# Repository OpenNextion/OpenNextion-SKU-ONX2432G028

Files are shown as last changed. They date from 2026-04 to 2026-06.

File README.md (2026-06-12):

[**English**](./README.md) | [简体中文](./README.zh-CN.md)

# ONX2432G028

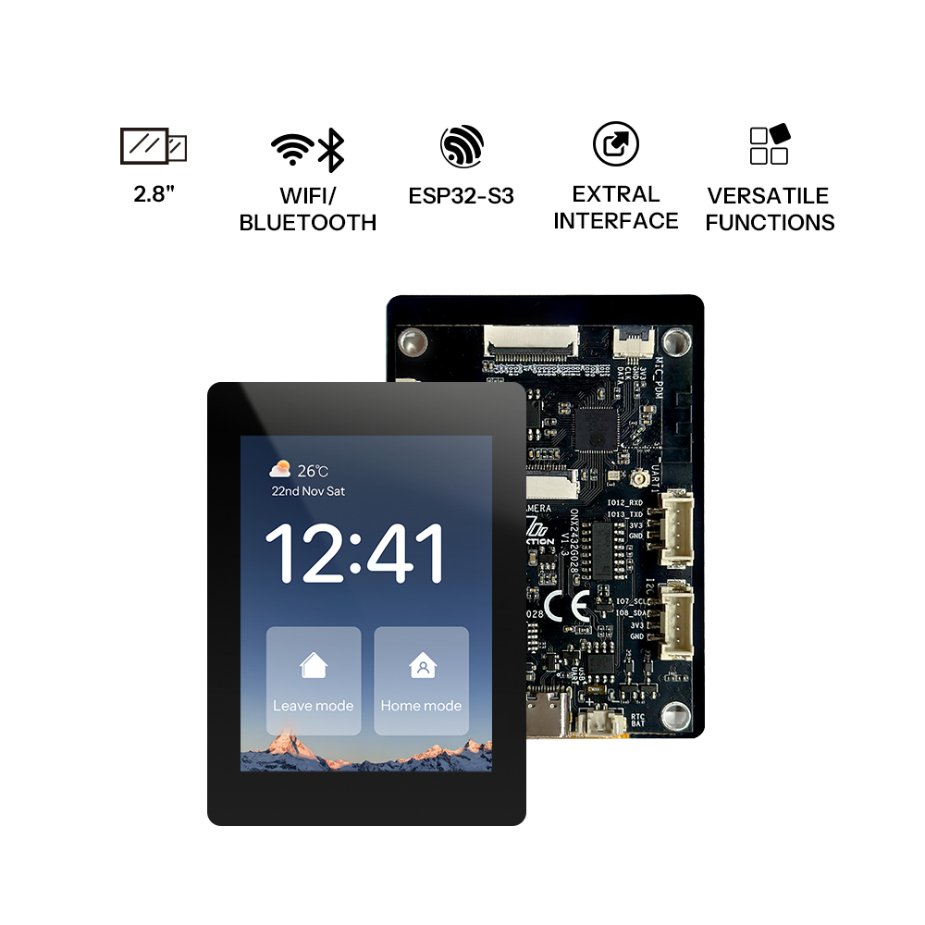
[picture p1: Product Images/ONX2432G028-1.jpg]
ONX2432G028


## Overview

`ONX2432G028` is a 2.8-inch Open Nextion HMI development board based on `ESP32-S3R8`. It integrates a capacitive touch display, `2.4 GHz Wi-Fi`, `Bluetooth 5 LE`, `MicroSD`, camera, microphone, speaker, battery management, and multiple expansion interfaces, making it suitable for HMI panels, IoT terminals, multimedia interaction, and rapid prototyping.

This repository collects product images, mechanical drawings, schematics, PCB files, certification documents, datasheets, USB-to-serial drivers, and example projects for both `ESP-IDF` and `ESP-Arduino`, so users can download and start development more easily.

## Purchase Links

- Product: [Open Nextion 2.8" Genius Series ESP32-S3 LCD Touchscreen Development Board](https://itead.cc/product/open-nextion-2-8-genius-series-esp32-s3-lcd-touchscreen-development-board/)
- Optional Audio Accessory: [Nextion BOX Speaker](https://itead.cc/product/nextion-box-speaker/)
- Optional Microphone Accessory: [Nextion Dual MIC Board](https://itead.cc/product/nextion-dual-mic-board/)
- Optional Expansion Accessory: [Nextion IO Adapter V2](https://itead.cc/product/nextion-io-adapter-v2/)

## Hardware Specifications

The following specifications are compiled from the official Wiki and the files included in this repository:

| Item | Specification |
| :--- | :--- |
| Model | `ONX2432G028` |
| MCU | `ESP32-S3R8`, Xtensa LX7 dual-core, up to `240 MHz` |
| Flash | `16 MB` |
| PSRAM | `8 MB` |
| Display Size | `2.8"` |
| Resolution | `240 x 320` |
| Colors | `262K` |
| Brightness | `300 nit` |
| Touch Type | Capacitive touch |
| LCD Driver | `ST7789` |
| Touch Driver | `CST826` |
| Wireless | `2.4 GHz Wi-Fi` + `Bluetooth 5 LE` |
| Power Input | `DC 5V/1A` |
| Battery Support | `3.7V` Li-ion battery interface with charging management, plus `3V` RTC backup battery support |
| Main Interfaces | `USB-C`, Grove `I2C`, Grove `UART1`, `MicroSD`, camera interface, PDM microphone interface, speaker interface, 24-pin GPIO, external antenna connector |
| Operating Temperature | `-20 to 70 C` |
| Storage Temperature | `-30 to 80 C` |
| Weight | Net weight about `47 g`, gross weight about `100.5 g` |

## Key Features

- Built on `ESP32-S3` for connected applications with graphical user interfaces.
- Onboard `2.8"` capacitive touch display, suitable for control panels, dashboards, and interactive terminals.
- Supports `MicroSD`, camera, `PDM` microphone, and speaker expansion for multimedia and voice-interaction projects.
- `USB-C` is used for power, firmware flashing, and serial logs, and supports automatic download mode.
- Includes an onboard antenna and a reserved external antenna connector for wireless applications.
- Supports Li-ion battery power and RTC backup battery, useful for portable and offline-clock scenarios.

## Repository Contents

| Folder | Description |
| :--- | :--- |
| `Certifications/` | Certification and compliance documents |
| `Datasheets/` | Datasheets for key components such as `ESP32-S3`, `ST7789`, `CST826`, `PCF8574`, and `IP4054V` |
| `Drawings/` | Mechanical dimension file, `2D` drawing, and `3D` model |
| `Example Programs/` | Example projects for `ESP-IDF` and `ESP-Arduino` |
| `LTA Announcement/` | Official announcement document |
| `Product Images/` | Product photos |
| `Schematic & Layout_/` | Schematics and PCB layout files |
| `USB-to-Serial Driver/` | USB-to-serial drivers for Windows, macOS, and Linux |

## Example Projects

`Example Programs/` contains two sets of ready-to-use examples:

- `ESP-IDF/`: native ESP-IDF projects, suitable for production firmware, component-based development, and projects that need the full ESP-IDF feature set.
- `ESP-Arduino/`: Arduino sketch projects, suitable for rapid prototyping, Arduino IDE users, and projects that prefer the ESP32 Arduino Core development workflow.

Most example folders include both Chinese and English documentation.

### ESP-IDF Examples

| Example Folder | Description |
| :--- | :--- |
| `01_touch_test` | Touch test for LCD and touch verification |
| `02_music_test` | Play audio from `MicroSD` with touch interaction |
| `03_sd_card_image_test` | Read and display images from `MicroSD` |
| `04_sd_card_test` | `MicroSD` mount, read/write, and card info test |
| `05_wifi_test` | Wi-Fi scan, connection, and status display |
| `06_camera_test` | Connect an `OV2640` camera and preview the image on screen |
| `07_microphone_test` | PDM microphone capture, speech front-end processing, and playback |
| `08_battery_test` | Battery voltage, battery level estimation, and charge status display |
| `09_outofbox_demo` | Factory demo for quickly verifying LCD, touch, and LVGL UI |

### ESP-Arduino Examples

`Example Programs/ESP-Arduino/` provides Arduino versions of the board examples. Each directory can be opened directly in Arduino IDE through its `.ino` file.

| Example Folder | Description |
| :--- | :--- |
| `01_touch_test` | LCD, CST826 touch, PCF8574 reset control, and LVGL touch-coordinate display test |
| `02_music_test` | Play `.mp3` files from the `/music` directory on `MicroSD`, show the LVGL music UI, and output through the speaker |
| `03_sd_card_image_test` | Scan and display `JPG`, `JPEG`, and `PNG` images from `MicroSD` |
| `04_sd_card_test` | Use `SD_MMC` to mount, write, read, and verify `MicroSD` content |
| `05_wifi_test` | Use the ESP32 Arduino `WiFi` library for Wi-Fi scanning and connection UI testing |
| `06_camera_test` | `OV2640` camera capture and live LCD preview |
| `07_microphone_test` | PDM microphone recording and I2S speaker playback |
| `08_battery_test` | Battery-voltage sampling, battery-level estimation, and charge-state display |
| `09_outofbox_demo` | Arduino port of the factory LVGL widgets demo |

## Quick Start

### 1. Install the Driver

If your computer does not recognize the serial device, install the appropriate driver from `USB-to-Serial Driver/`:

- Windows: `CH340K-USB-to-UART-Driver.zip`
- macOS: `CH341SER_MAC.ZIP`
- Linux: `CH341SER_LINUX.zip`

### 2. Connect the Board

Use a `USB-C` cable to connect the board to your computer. The `USB-C` port can be used for:

- Power supply
- Firmware flashing
- Serial log output

### 3. Choose a Development Environment

- Use `Example Programs/ESP-IDF/` if you prefer Espressif's native framework, component-based projects, and `idf.py`.
- Use `Example Programs/ESP-Arduino/` if you prefer Arduino IDE or `arduino-cli` sketches.

After choosing an example folder, check the included `README_zh.md` or `README_en.md` and prepare the required peripherals, such as a `MicroSD` card, camera, microphone, or speaker.

### 4. Set Up the Development Environment

For `ESP-IDF`, the included examples indicate:

- Development version: `ESP-IDF 5.4.1`
- Recommended version: `ESP-IDF >= 5.4.0`

For `ESP-Arduino`, install the ESP32 Arduino core and select:

- Board: `ESP32S3 Dev Module`
- Flash Size: `16MB (128Mb)`
- PSRAM: `OPI PSRAM`
- Partition Scheme: `16M Flash (3MB APP/9.9MB FATFS)`

Install the libraries listed in the selected example's README before compiling.

### 5. Build and Flash an ESP-IDF Example

Example using the out-of-box demo:

```bash
cd "Example Programs/ESP-IDF/09_outofbox_demo"
idf.py set-target esp32s3
idf.py build
idf.py -p <PORT> flash monitor
```

If flashing fails on the first attempt, hold the `BOOT` button and press `RESET` once to enter download mode, then try again.

### 6. Build and Upload an ESP-Arduino Example

Example using the Arduino out-of-box demo:

```bash
arduino-cli compile --fqbn esp32:esp32:esp32s3:FlashSize=16M,PartitionScheme=app3M_fat9M_16MB,PSRAM=opi "Example Programs/ESP-Arduino/09_outofbox_demo"
arduino-cli upload -p <PORT> --fqbn esp32:esp32:esp32s3:FlashSize=16M,PartitionScheme=app3M_fat9M_16MB,PSRAM=opi "Example Programs/ESP-Arduino/09_outofbox_demo"
```

You can also open the corresponding `.ino` file directly in Arduino IDE and use the board settings above.

## Notes

- `USB_UART` and `UART0` share the same `TX/RX` signals and cannot be used at the same time.
- The 24-pin GPIO expansion shares signals with `UART1`, `MIC_PDM`, and `CAMERA`, so check pin multiplexing before use.
- `USB-C` supports automatic download mode, while `UART0` does not.
- Wi-Fi supports `2.4 GHz` only.
- The speaker interface supports up to `2W`.
- If you need an external antenna, follow the official hardware instruction to switch the RF path by desoldering the corresponding resistor.
- The board itself is not waterproof. If needed, use a custom enclosure.
- For mechanical dimensions, see `Drawings/ONX2432G028_Dimension.pdf`.
- For detailed circuit design, see the files under `Schematic & Layout_/V1.3/`.

## References

- Official product page: [ONX2432G028 Wiki](https://nextion.tech/wiki/onx2432g028/)
- ESP-IDF getting started: [ESP32-S3 Getting Started](https://docs.espressif.com/projects/esp-idf/en/stable/esp32s3/get-started/)

If you are starting development on this board, it is recommended to begin with `09_outofbox_demo` or `01_touch_test` in either `ESP-IDF` or `ESP-Arduino` to verify the screen, touch, and basic environment first, then move on to `Wi-Fi`, `MicroSD`, camera, or audio-related features.

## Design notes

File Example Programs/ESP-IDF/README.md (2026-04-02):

# ESP32S3-NEXTION-EXAMPLE

This directory contains example projects for the ESP32-S3 development board (ONX2432G028), covering peripherals such as LCD touch, camera, audio, SD card, Wi-Fi, and battery. For details of each example, see the README in the corresponding example folder.

## Purchase Links

- Product: [Open Nextion 2.8" Genius Series ESP32-S3 LCD Touchscreen Development Board](https://itead.cc/product/open-nextion-2-8-genius-series-esp32-s3-lcd-touchscreen-development-board/)
- Optional Audio Accessory: [Nextion BOX Speaker](https://itead.cc/product/nextion-box-speaker/)
- Optional Microphone Accessory: [Nextion Dual MIC Board](https://itead.cc/product/nextion-dual-mic-board/)
- Optional Expansion Accessory: [Nextion IO Adapter V2](https://itead.cc/product/nextion-io-adapter-v2/)

> Note: This project was developed with ESP-IDF 5.4.1. It is recommended to use ESP-IDF version >= 5.4.0

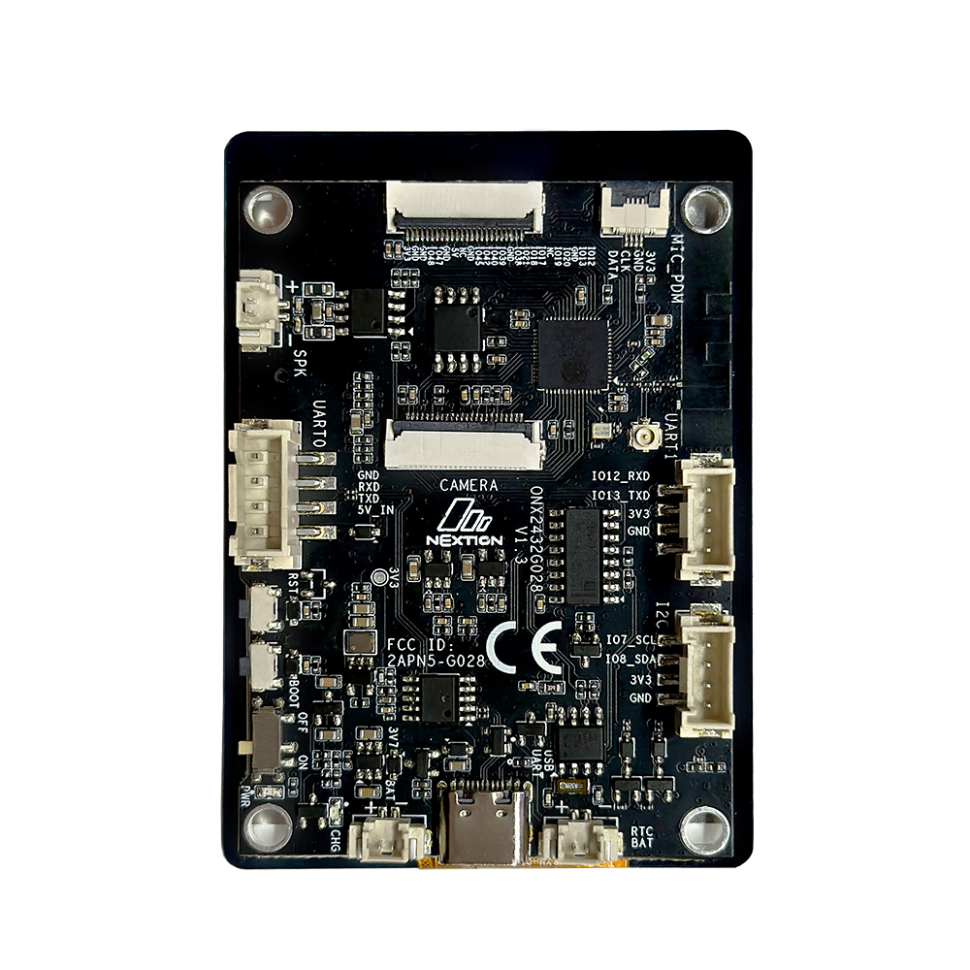
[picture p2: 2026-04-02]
Product Images/ONX2432G028-3.jpg

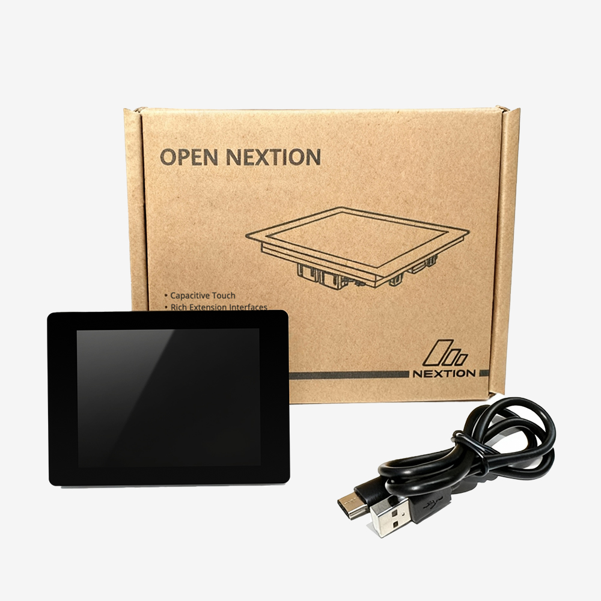
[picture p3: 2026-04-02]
Product Images/ONX2432G028-4.jpg

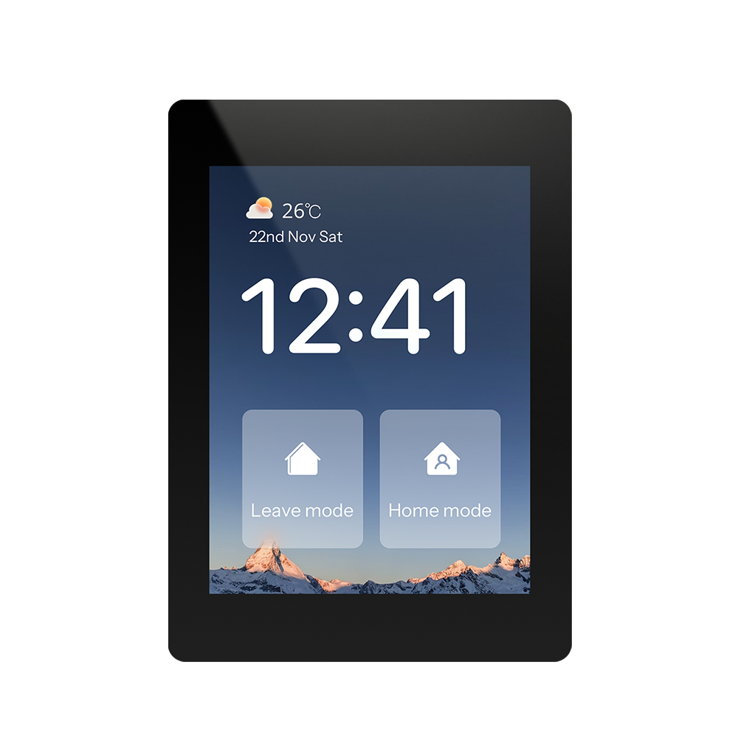
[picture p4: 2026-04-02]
Product Images/ONX2432G028-2.jpg

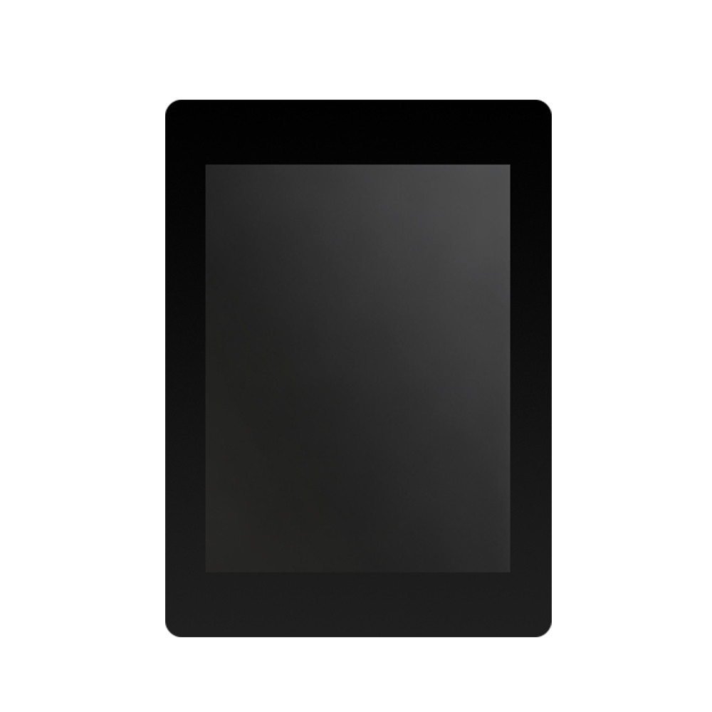
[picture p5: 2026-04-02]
Product Images/ONX2432G028-5.jpg

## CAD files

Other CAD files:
Drawings/ONX2432G028_2D_File.dwg

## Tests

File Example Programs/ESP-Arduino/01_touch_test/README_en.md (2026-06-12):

# ESP32-S3 Arduino Touch Test Example

## Overview

This is the ESP-Arduino version of `01_touch_test` for the ONX2432G028 2.8-inch display board. It uses standard Arduino libraries for the hardware drivers and LVGL for UI rendering:

- LCD: `Arduino_ST7789` from `GFX Library for Arduino`
- Touch: `Adafruit CST8XX Library`
- IO expander: `Adafruit PCF8574`
- UI: `lvgl`

The screen shows a white background and a gray `Touch Test` label. When the panel is touched, the sketch draws a red 4x4 pixel square at the touch position and prints the touch coordinates to the serial monitor.

LVGL renders the UI text. The touch trail follows the ESP-IDF example approach: it draws 4x4 red blocks directly through the LCD driver, avoiding unbounded LVGL object creation during long touch tests.

## Files

- `01_touch_test.ino`: Main sketch, directly openable in Arduino IDE.
- `BoardConfig.h`: Board pins, resolution, and I2C addresses.
- `build_opt.h`: Arduino ESP32 build options used to make LVGL use its built-in default configuration.

## Hardware Pins

| Function | ESP32-S3 Pin |
| :--- | :--- |
| I2C SCL | GPIO7 |
| I2C SDA | GPIO8 |
| LCD SCLK | GPIO5 |
| LCD MOSI | GPIO1 |
| LCD DC | GPIO3 |
| LCD CS | GPIO2 |
| LCD BL | GPIO6 |
| LCD RST | PCF8574 P6 |

## Arduino IDE Setup

1. Install the ESP32 Arduino core.
2. Install these libraries: `GFX Library for Arduino`, `Adafruit CST8XX Library`, `Adafruit PCF8574`, and `lvgl`.
3. Open `ONX2432G028/ESP-Arduino/01_touch_test/01_touch_test.ino`.
4. Select `ESP32S3 Dev Module`.
5. Recommended settings:
   - USB CDC On Boot: Enabled
   - Flash Size: `16MB (128Mb)`
   - PSRAM: `OPI PSRAM`
   - Partition Scheme: `16M Flash (3MB APP/9.9MB FATFS)`
6. Compile and upload.
7. Open the serial monitor at 115200 baud to view touch coordinates.

## Display Direction

The display direction can be configured at the top of `01_touch_test.ino`:

```cpp
#define DISPLAY_SWAP_XY false
#define DISPLAY_MIRROR_X true
#define DISPLAY_MIRROR_Y false
```

The default values are the direction settings verified on ONX2432G028 hardware. Arduino_GFX rotation IDs do not map one-to-one to ESP-IDF `swap_xy` / `mirror_x` / `mirror_y`, so the sketch translates the macros through `displayRotationFromConfig()`.

## Implementation Notes

- LCD reset is controlled by PCF8574 P6. Other expander pins are kept high during reset to avoid disturbing shared peripherals.
- LVGL renders the initial UI and label. Root-screen scrolling is disabled so edge touches do not drag the page.
- Touch dots are drawn directly with `Arduino_GFX`, similar to the ESP-IDF example's `esp_lcd_panel_draw_bitmap()` path.
- This example does not add a custom Arduino driver library. LCD, touch, IO expander, and UI are handled by standard Arduino libraries or third-party libraries.

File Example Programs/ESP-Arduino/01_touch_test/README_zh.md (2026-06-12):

# ESP32-S3 Arduino 触摸测试示例

## 概述

本示例是 `01_touch_test` 的 ESP-Arduino 版本，用于 ONX2432G028 开发板的 2.8 寸屏基础触摸测试。程序使用 Arduino 标准库生态完成硬件驱动和 UI 绘制：

- LCD：`GFX Library for Arduino` 的 `Arduino_ST7789`
- 触摸：`Adafruit CST8XX Library`
- IO 扩展：`Adafruit PCF8574`
- UI：`lvgl`

屏幕显示白色背景和灰色 `Touch Test` 文本。触摸屏幕时，程序会在触点位置绘制红色 4x4 像素方块，并在串口监视器输出触摸坐标。

UI 文本由 LVGL 绘制；触摸轨迹参考 ESP-IDF 例程的实现方式，使用 LCD 驱动直接刷 4x4 红色小块，避免连续触摸时创建大量 LVGL 对象导致内存增长。

## 文件

- `01_touch_test.ino`: Arduino IDE 可直接打开的主程序。
- `BoardConfig.h`: 板级引脚、分辨率和 I2C 地址配置。
- `build_opt.h`: Arduino ESP32 编译选项，用于让 LVGL 使用内置默认配置。

## 硬件引脚

| 功能 | ESP32-S3 引脚 |
| :--- | :--- |
| I2C SCL | GPIO7 |
| I2C SDA | GPIO8 |
| LCD SCLK | GPIO5 |
| LCD MOSI | GPIO1 |
| LCD DC | GPIO3 |
| LCD CS | GPIO2 |
| LCD BL | GPIO6 |
| LCD RST | PCF8574 P6 |

## Arduino IDE 设置

1. 安装 ESP32 Arduino core。
2. 安装库：`GFX Library for Arduino`、`Adafruit CST8XX Library`、`Adafruit PCF8574`、`lvgl`。
3. 打开 `ONX2432G028/ESP-Arduino/01_touch_test/01_touch_test.ino`。
4. 开发板选择 `ESP32S3 Dev Module`。
5. 建议设置：
   - USB CDC On Boot: Enabled
   - Flash Size: `16MB (128Mb)`
   - PSRAM: `OPI PSRAM`
   - Partition Scheme: `16M Flash (3MB APP/9.9MB FATFS)`
6. 编译并烧录。
7. 打开 115200 波特率串口监视器查看触摸坐标。

## 屏幕方向

屏幕方向可在 `01_touch_test.ino` 顶部通过以下宏配置：

```cpp
#define DISPLAY_SWAP_XY false
#define DISPLAY_MIRROR_X true
#define DISPLAY_MIRROR_Y false
```

当前默认值为 ONX2432G028 实机验证后的方向配置。Arduino_GFX 的 rotation 编码与 ESP-IDF 的 `swap_xy` / `mirror_x` / `mirror_y` 不完全同名，因此程序通过 `displayRotationFromConfig()` 做一次映射。

## 实现说明

- LCD 复位通过 PCF8574 P6 控制，初始化时保持其它扩展 IO 为高电平，避免影响共用扩展 IO 的外设。
- LVGL 负责初始界面和文字显示，根页面禁用滚动，避免触摸边缘时页面被拖动。
- 红点使用 `Arduino_GFX` 直接刷屏绘制，行为接近 ESP-IDF 例程中的 `esp_lcd_panel_draw_bitmap()`。
- 本例程不包含自定义 Arduino 驱动库，LCD、触摸、IO 扩展和 UI 均使用标准 Arduino 库或第三方库。

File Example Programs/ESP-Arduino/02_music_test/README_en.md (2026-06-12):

# ESP32-S3 Arduino Music Test Example

## Overview

This is the ESP-Arduino version of `02_music_test` for the ONX2432G028 board.

It uses standard Arduino/ESP32 libraries and third-party libraries:

- LCD: `Arduino_ST7789` from `GFX Library for Arduino`
- Touch: `Adafruit CST8XX Library`
- IO expander: `Adafruit PCF8574`
- SD card: `SD_MMC` from the ESP32 Arduino core
- UI: `lvgl`, with the Music Demo UI assets ported from the ESP-IDF `components/gui`
- Audio playback: `ESP32-audioI2S-master`

The sketch mounts the SD card, scans `/music` for `.mp3` files, and displays the same LVGL Music Demo style as the ESP-IDF example: cover art, spectrum, track metadata, playback controls, and the ALL TRACKS list. Tapping a track plays it through the onboard NS4168 speaker amplifier.

## Notes

This Arduino version matches the ESP-IDF UI and uses a proven third-party library for MP3 decoding and I2S playback. It does not implement a custom audio decoder.

For the ONX2432G028 240 x 320 display, this sketch keeps the ESP-IDF Music Demo assets and only applies the required small-screen adaptation:

- Display direction matches the verified `01_touch_test` configuration: `DISPLAY_SWAP_XY=false`, `DISPLAY_MIRROR_X=true`, `DISPLAY_MIRROR_Y=false`.
- Extra scrollbars are disabled so the main page stays inside the screen bounds.
- Previous, play/pause, and next buttons are spaced farther apart to reduce accidental taps on the 2.8-inch panel.
- Cover art is scaled for the 2.8-inch screen while keeping the ESP-IDF layout and visual assets.

## Audio And Pop Suppression

- I2S BCLK: GPIO14
- I2S LRCLK/WS: GPIO16
- I2S DOUT/SDATA: GPIO15
- NS4168 enable: PCF8574 `I2S_CTRL`

PCF8574 ports default high after power-up. If `I2S_CTRL` is enabled too early, the speaker may pop before I2S output is stable. This sketch follows the same mitigation used by the tested 3.5-inch Arduino example:

- After PCF8574 initialization, the sketch immediately writes the shadow register with `I2S_CTRL=LOW`.
- LCD reset, SD CS, and other PCF8574 output changes all go through the shadow register so the amplifier enable bit is not changed accidentally.
- The NS4168 amplifier is enabled only after MP3 decoding and I2S output have started and settled.
- The amplifier is muted before pause, track switching, and playback restart to reduce switching transients.

## ESP32S3R8 + 16 MB Flash Settings

This sketch ports the complete LVGL Music UI images and fonts from the ESP-IDF example, so it is larger than Arduino's default `1.2 MB APP` partition. For ESP32S3R8 with external 16 MB flash, use these Arduino IDE settings:

- Board: `ESP32S3 Dev Module`
- Flash Size: `16MB (128Mb)`
- PSRAM: `OPI PSRAM`
- Partition Scheme: `16M Flash (3MB APP/9.9MB FATFS)`

The project includes `sketch.yaml` as a record of the target board settings. With the current Arduino CLI, `--profile` may skip the locally installed library search path, so use the verified full FQBN:

```bash
arduino-cli compile --fqbn esp32:esp32:esp32s3:FlashSize=16M,PartitionScheme=app3M_fat9M_16MB,PSRAM=opi ESP-Arduino/02_music_test
arduino-cli upload --fqbn esp32:esp32:esp32s3:FlashSize=16M,PartitionScheme=app3M_fat9M_16MB,PSRAM=opi -p <your port> ESP-Arduino/02_music_test
```

## Files

- `02_music_test.ino`: Main Arduino sketch.
- `BoardConfig.h`: Board pins, resolution, I2C addresses, SD pins, and I2S pins.
- `build_opt.h`: LVGL build option.
- `sketch.yaml`: Target board setting record for ESP32S3R8 + 16 MB flash.
- `src/gui`: LVGL Music UI source and assets ported from the ESP-IDF example.
- `src/gui/gui_hal.cpp`: Arduino adapter for SD_MMC scanning, MP3 playback, volume mapping, and amplifier timing.

## SD Card Layout

Create this folder in the SD card root:

```text
/music
```

Then copy `.mp3` files into it.

If no SD card is detected, or if `/music` does not exist or contains no `.mp3` files, the screen shows a red hint instead of entering the player UI.

## Dependencies

Install these libraries from Arduino IDE Library Manager:

- `GFX Library for Arduino`
- `Adafruit CST8XX Library`
- `Adafruit PCF8574`
- `lvgl` 8.3.x
- `ESP32-audioI2S-master`

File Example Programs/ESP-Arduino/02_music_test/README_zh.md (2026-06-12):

# ESP32-S3 Arduino 音乐测试示例

## 概述

本示例是 `02_music_test` 的 ESP-Arduino 版本，用于 ONX2432G028 开发板的基础音乐文件测试。

程序使用标准 Arduino/ESP32 库和第三方库：

- LCD：`GFX Library for Arduino` 的 `Arduino_ST7789`
- 触摸：`Adafruit CST8XX Library`
- IO 扩展：`Adafruit PCF8574`
- SD 卡：ESP32 Arduino core 的 `SD_MMC`
- UI：`lvgl`，并移植 ESP-IDF 版本 `components/gui` 的 Music Demo 界面资源
- 音频播放：`ESP32-audioI2S-master`

示例会挂载 SD 卡，扫描 `/music` 目录中的 `.mp3` 文件，并使用与 ESP-IDF 版本同源的 LVGL Music Demo UI 显示封面、波形、曲目信息、播放控制和 ALL TRACKS 列表。点击曲目后会通过 I2S 输出到板载 NS4168 喇叭功放。

## 说明

当前 Arduino 版本已对齐 ESP-IDF 版本的 UI 效果，并使用成熟第三方库完成 MP3 解码和 I2S 播放，没有自写音频解码器。

针对 ONX2432G028 的 240 x 320 屏幕，本例程沿用 ESP-IDF 的 Music Demo 资源，只做了必要的尺寸适配：

- 屏幕方向与 `01_touch_test` 已验证方向一致：`DISPLAY_SWAP_XY=false`、`DISPLAY_MIRROR_X=true`、`DISPLAY_MIRROR_Y=false`。
- 主播放页关闭多余滚动条，避免页面尺寸超过屏幕边界。
- 上一首、播放/暂停、下一首按钮之间增加间隔，降低 2.8 寸屏幕上的误触概率。
- 封面图按 2.8 寸屏幕缩放，保留 ESP-IDF 版本的界面布局和视觉资源。

## 音频与防爆破声

- I2S BCLK: GPIO14
- I2S LRCLK/WS: GPIO16
- I2S DOUT/SDATA: GPIO15
- NS4168 使能：PCF8574 `I2S_CTRL`

PCF8574 上电默认端口为高电平，若过早打开 `I2S_CTRL`，喇叭可能在 I2S 输出稳定前产生瞬间爆破声。本例程参考 3.5 寸 Arduino 例程的修复方式：

- PCF8574 初始化后立即写入影子寄存器，保持 `I2S_CTRL=LOW`。
- LCD 复位、SD CS 等 PCF8574 引脚操作都通过影子寄存器完成，避免误改功放使能位。
- MP3 解码和 I2S 输出启动后再延迟打开 NS4168 功放。
- 暂停、切歌和重新开始播放前先关闭功放，减少切换瞬态声。

## ESP32S3R8 + 16MB Flash 配置

本例程移植了 ESP-IDF 版本的完整 LVGL Music UI 图片和字体资源，程序体积超过 Arduino 默认 `1.2MB APP` 分区。你的硬件为 ESP32S3R8 + 外挂 16MB Flash，请在 Arduino IDE 中选择：

- Board: `ESP32S3 Dev Module`
- Flash Size: `16MB (128Mb)`
- PSRAM: `OPI PSRAM`
- Partition Scheme: `16M Flash (3MB APP/9.9MB FATFS)`

工程内提供了 `sketch.yaml` 记录目标配置。当前 Arduino CLI 版本使用 `--profile` 时可能不加载本机已安装库路径，推荐使用已验证的完整 FQBN：

```bash
arduino-cli compile --fqbn esp32:esp32:esp32s3:FlashSize=16M,PartitionScheme=app3M_fat9M_16MB,PSRAM=opi ESP-Arduino/02_music_test
arduino-cli upload --fqbn esp32:esp32:esp32s3:FlashSize=16M,PartitionScheme=app3M_fat9M_16MB,PSRAM=opi -p <你的串口> ESP-Arduino/02_music_test
```

## 文件

- `02_music_test.ino`: Arduino 主程序。
- `BoardConfig.h`: 板级引脚、分辨率、I2C 地址和 SD/I2S 引脚配置。
- `build_opt.h`: LVGL 编译选项。
- `sketch.yaml`: ESP32S3R8 + 16MB Flash 的目标配置记录。
- `src/gui`: 从 ESP-IDF 版本移植的 LVGL Music UI 源码和资源。
- `src/gui/gui_hal.cpp`: Arduino 适配层，负责 SD_MMC 扫描、MP3 播放、音量映射和功放时序控制。

## SD 卡目录

请在 SD 卡根目录创建：

```text
/music
```

并放入 `.mp3` 文件。

如果未检测到 SD 卡，或 `/music` 目录不存在/没有 `.mp3` 文件，屏幕会显示红色提示文字，不进入音乐播放界面。

## 依赖库

请在 Arduino IDE 的 Library Manager 中安装：

- `GFX Library for Arduino`
- `Adafruit CST8XX Library`
- `Adafruit PCF8574`
- `lvgl` 8.3.x
- `ESP32-audioI2S-master`

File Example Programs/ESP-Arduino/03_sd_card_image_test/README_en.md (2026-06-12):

# ESP32-S3 Arduino SD Card Image Test Example

## Overview

This is the ESP-Arduino version of `03_sd_card_image_test`. It tests SD-card image-file scanning and full-screen image browsing.

Libraries used:

- LCD: `GFX Library for Arduino`
- Touch: `Adafruit CST8XX Library`
- IO expander: `Adafruit PCF8574`
- SD card: `SD_MMC` from the ESP32 Arduino core
- UI: `lvgl`
- JPG/JPEG decoding: Espressif JPEG decoder bundled with the ESP32 Arduino core
- PNG decoding: LVGL bundled `lodepng`

The sketch scans `/images` for image files. When images are found, it opens a full-screen image viewer. Swipe left/right to switch to the previous or next image. If no SD card is inserted, no images are found, or an image cannot be decoded, the sketch shows a centered red prompt on a white background. Prompt text is wrapped for the 240-pixel display width.

## Notes

This version does not implement a custom image decoder. JPG/JPEG files are decoded with `esp_jpeg_decode()` from the ESP32 Arduino core, and PNG files are decoded with LVGL's bundled `lodepng`. Images are fully decoded into a PSRAM frame buffer before the LCD is updated in bands, which avoids visible top-to-bottom decode refresh on the panel.

Images use a fixed width-fit policy: regardless of the source orientation, the image is scaled to the 240-pixel screen width and vertically centered. Other extensions are scanned for compatibility with the ESP-IDF directory rules, but the current Arduino version directly renders JPG/JPEG/PNG only; unsupported formats show a decode-failed message.

This example uses the same verified display direction as `01_touch_test`:

```cpp
#define DISPLAY_SWAP_XY false
#define DISPLAY_MIRROR_X true
#define DISPLAY_MIRROR_Y false
```

`build_opt.h` enables `LV_USE_PNG` and `LV_MEM_CUSTOM` so LVGL builds PNG support and the PNG decoder can allocate from the configured external-memory path.

## SD Card Layout

Create this folder in the SD card root:

```text
/images
```

Then copy image files into it.

Recommended formats:

```text
.jpg
.jpeg
.png
```

If the SD card is missing, the screen shows `No SD card detected...`. If `/images` does not exist or contains no scannable image files, the screen shows `Image not found.`.

## Arduino IDE Settings

When opening this example in Arduino IDE, use:

- Board: `ESP32S3 Dev Module`
- Flash Size: `16MB (128Mb)`
- PSRAM: `OPI PSRAM`
- Partition Scheme: `16M Flash (3MB APP/9.9MB FATFS)`

Arduino CLI build/upload example:

```bash
arduino-cli compile --fqbn esp32:esp32:esp32s3:FlashSize=16M,PartitionScheme=app3M_fat9M_16MB,PSRAM=opi ONX2432G028/ESP-Arduino/03_sd_card_image_test
arduino-cli upload -p <your port> --fqbn esp32:esp32:esp32s3:FlashSize=16M,PartitionScheme=app3M_fat9M_16MB,PSRAM=opi ONX2432G028/ESP-Arduino/03_sd_card_image_test
```

## Files

- `03_sd_card_image_test.ino`: Main Arduino sketch, including board initialization, SD scanning, image decoding, scaling, and swipe handling.
- `BoardConfig.h`: ONX2432G028 LCD, I2C, PCF8574, and SD_MMC pin configuration.
- `build_opt.h`: LVGL/PNG build options.
- `sketch.yaml`: Target setting record for ESP32S3R8 + 16 MB flash.

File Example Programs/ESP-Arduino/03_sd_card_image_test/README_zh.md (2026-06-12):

# ESP32-S3 Arduino SD 卡图片测试示例

## 概述

本示例是 `03_sd_card_image_test` 的 ESP-Arduino 版本，用于测试 SD 卡图片文件扫描和全屏图片浏览。

使用的库：

- LCD：`GFX Library for Arduino`
- 触摸：`Adafruit CST8XX Library`
- IO 扩展：`Adafruit PCF8574`
- SD 卡：ESP32 Arduino core 的 `SD_MMC`
- UI：`lvgl`
- JPG/JPEG 解码：ESP32 Arduino core 内置的 Espressif JPEG decoder
- PNG 解码：LVGL 内置 `lodepng`

程序会扫描 SD 卡 `/images` 目录中的图片文件。找到图片后会进入全屏图片浏览界面，左右滑动切换上一张/下一张。未插 SD 卡、未找到图片或图片解码失败时，会显示白底红字的居中提示页面，提示文字已按 240 像素屏幕宽度自动换行。

## 说明

当前版本不自写图片解码器，JPG/JPEG 使用 ESP32 Arduino core 提供的 `esp_jpeg_decode()`，PNG 使用 LVGL 自带的 `lodepng`。图片会先完整解码到 PSRAM 帧缓冲，再一次性分段刷新到 LCD，避免屏幕出现明显的从上到下解码刷新过程。

图片显示策略为固定宽度适配：无论图片原始方向如何，都会按屏幕宽度缩放到 240 像素宽，并在垂直方向居中显示。其他扩展名会参与扫描以兼容 ESP-IDF 版本的目录规则，但 Arduino 版本当前只直接渲染 JPG/JPEG/PNG；遇到暂未支持的格式时屏幕会显示解码失败提示。

本例程使用与 `01_touch_test` 一致的屏幕方向配置：

```cpp
#define DISPLAY_SWAP_XY false
#define DISPLAY_MIRROR_X true
#define DISPLAY_MIRROR_Y false
```

`build_opt.h` 中启用了 `LV_USE_PNG` 和 `LV_MEM_CUSTOM`，用于让 LVGL 编译 PNG 支持，并让 PNG 解码输出使用可用的外部内存配置。

## SD 卡目录

请在 SD 卡根目录创建：

```text
/images
```

并放入图片文件。

推荐优先放入：

```text
.jpg
.jpeg
.png
```

如果 SD 卡未插入，屏幕显示 `No SD card detected...`；如果 `/images` 目录不存在或目录中没有可扫描的图片文件，屏幕显示 `Image not found.`。

## Arduino IDE 设置

使用 Arduino IDE 打开本例程时，开发板建议选择：

- Board: `ESP32S3 Dev Module`
- Flash Size: `16MB (128Mb)`
- PSRAM: `OPI PSRAM`
- Partition Scheme: `16M Flash (3MB APP/9.9MB FATFS)`

也可以使用 Arduino CLI 编译/烧录：

```bash
arduino-cli compile --fqbn esp32:esp32:esp32s3:FlashSize=16M,PartitionScheme=app3M_fat9M_16MB,PSRAM=opi ONX2432G028/ESP-Arduino/03_sd_card_image_test
arduino-cli upload -p <你的串口> --fqbn esp32:esp32:esp32s3:FlashSize=16M,PartitionScheme=app3M_fat9M_16MB,PSRAM=opi ONX2432G028/ESP-Arduino/03_sd_card_image_test
```

## 文件说明

- `03_sd_card_image_test.ino`: Arduino 主程序，包含板级初始化、SD 卡扫描、图片解码、缩放显示和触摸滑动。
- `BoardConfig.h`: ONX2432G028 的 LCD、I2C、PCF8574 和 SD_MMC 引脚配置。
- `build_opt.h`: LVGL/PNG 相关编译选项。
- `sketch.yaml`: 记录 ESP32S3R8 + 16MB Flash 的目标配置。

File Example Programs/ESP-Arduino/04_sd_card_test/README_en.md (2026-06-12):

# ESP32-S3 Arduino SD Card Test Example

## Overview

This is the ESP-Arduino version of `04_sd_card_test`. It tests SD-card mounting, writing, reading, and verification.

Libraries used:

- LCD: `GFX Library for Arduino`
- Touch: `Adafruit CST8XX Library`
- IO expander: `Adafruit PCF8574`
- SD card: `SD_MMC` from the ESP32 Arduino core
- UI: `lvgl`

After tapping the `SD CARD TEST` button, the sketch re-detects and mounts the SD card, writes `/SD CARD TEST.txt` to the SD card root, reads it back, and compares the content. It shows `WRITE SUCCESS` when the readback matches, `NO SD CARD DETECTED` when no card is present, and an error message for other read/write failures.

The ONX2432G028 display is 240 pixels wide. Result and detail labels are limited to 216 pixels and use LVGL word wrapping so long strings such as `NO SD CARD DETECTED` and file paths do not overflow the screen.

## Test Flow

1. Initialize the LCD, CST826 touch controller, PCF8574 IO expander, and LVGL.
2. Tap the `SD CARD TEST` button.
3. Release the previous `SD_MMC` mount state and mount the SD card again.
4. Write a random string to `/SD CARD TEST.txt`.
5. Close the file, reopen it, and read the content back.
6. Compare the written and readback strings, then show the result on screen.

With this flow, removing the SD card after one successful test is handled on the next tap and shows `NO SD CARD DETECTED`.

## SD Card Notes

- The sketch uses `SD_MMC` from the ESP32 Arduino core in 1-bit mode.
- `/SD CARD TEST.txt` is created or overwritten in the SD card root.
- The file content is similar to `SD CARD TEST RAND NUM 12345678` and changes on every tap.
- The SD card is remounted on every button tap, so removing the card after one successful test shows `NO SD CARD DETECTED` on the next tap.

## Display And Touch

- Display direction matches `01_touch_test`: `DISPLAY_SWAP_XY=false`, `DISPLAY_MIRROR_X=true`, `DISPLAY_MIRROR_Y=false`.
- The result page uses a white background and centered text.
- Keep all user-visible text narrower than the screen and enable wrapping; avoid fixed text widths of 240 px or more on this 2.8-inch board.

## Arduino IDE Settings

When opening this example in Arduino IDE, use:

- Board: `ESP32S3 Dev Module`
- Flash Size: `16MB (128Mb)`
- PSRAM: `OPI PSRAM`
- Partition Scheme: `16M Flash (3MB APP/9.9MB FATFS)`

## Files

- `04_sd_card_test.ino`: Main Arduino sketch.
- `BoardConfig.h`: Board pins, resolution, and SD-card pins.
- `build_opt.h`: LVGL build option; it currently skips the default `lv_conf.h`.
- `sketch.yaml`: Target setting record for ESP32S3R8 + 16 MB flash.

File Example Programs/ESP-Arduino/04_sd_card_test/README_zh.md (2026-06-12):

# ESP32-S3 Arduino SD 卡读写测试示例

## 概述

本示例是 `04_sd_card_test` 的 ESP-Arduino 版本，用于测试 SD 卡挂载、写入、读回和校验。

使用的库：

- LCD：`GFX Library for Arduino`
- 触摸：`Adafruit CST8XX Library`
- IO 扩展：`Adafruit PCF8574`
- SD 卡：ESP32 Arduino core 的 `SD_MMC`
- UI：`lvgl`

点击屏幕上的 `SD CARD TEST` 按钮后，程序会先重新检测并挂载 SD 卡，然后向 SD 卡根目录写入 `/SD CARD TEST.txt`，再读回内容并比较。如果一致，显示 `WRITE SUCCESS`；如果未检测到 SD 卡，显示 `NO SD CARD DETECTED`；其他读写异常显示错误信息。

ONX2432G028 屏幕宽度为 240 像素，本例程中的结果文字和详情文字统一限制为 216 像素宽，并启用 LVGL 自动换行，避免 `NO SD CARD DETECTED`、文件路径等较长文本超出屏幕边界。

## 测试流程

1. 初始化 LCD、CST826 触摸、PCF8574 IO 扩展和 LVGL。
2. 点击 `SD CARD TEST` 按钮。
3. 释放上一次的 `SD_MMC` 挂载状态，并重新挂载 SD 卡。
4. 写入随机字符串到 `/SD CARD TEST.txt`。
5. 关闭文件后重新打开并读回内容。
6. 比较写入和读回内容，并在屏幕上显示测试结果。

这样处理后，插卡测试成功后再拔卡，下一次点击会重新检测 SD 卡并显示 `NO SD CARD DETECTED`。

## SD 卡说明

- 使用 ESP32 Arduino core 的 `SD_MMC`，配置为 1-bit 模式。
- SD 卡根目录会生成或覆盖 `/SD CARD TEST.txt`。
- 测试文件内容类似 `SD CARD TEST RAND NUM 12345678`，每次点击都会更新。
- 每次点击按钮都会重新挂载 SD 卡，因此先插卡测试成功、再拔卡测试时，会显示 `NO SD CARD DETECTED`。

## 显示与触摸

- 屏幕方向与 `01_touch_test` 保持一致：`DISPLAY_SWAP_XY=false`、`DISPLAY_MIRROR_X=true`、`DISPLAY_MIRROR_Y=false`。
- 结果页背景为白色，结果文字居中显示。
- 所有用户可见文本都应小于屏幕宽度并启用换行；后续修改 UI 时不要使用 240 像素以上的固定文本宽度。

## Arduino IDE 设置

使用 Arduino IDE 打开本例程时，开发板建议选择：

- Board: `ESP32S3 Dev Module`
- Flash Size: `16MB (128Mb)`
- PSRAM: `OPI PSRAM`
- Partition Scheme: `16M Flash (3MB APP/9.9MB FATFS)`

## 文件

- `04_sd_card_test.ino`: Arduino 主程序。
- `BoardConfig.h`: 板级引脚、分辨率和 SD 卡引脚配置。
- `build_opt.h`: LVGL 编译选项，当前仅跳过默认 `lv_conf.h`。
- `sketch.yaml`: 记录 ESP32S3R8 + 16MB Flash 的目标配置。

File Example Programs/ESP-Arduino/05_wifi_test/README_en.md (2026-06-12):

# ESP32-S3 Arduino WiFi Test Example

## Overview

This is the ESP-Arduino version of `05_wifi_test`. It tests WiFi scanning and a basic connection UI.

Libraries used:

- LCD: `GFX Library for Arduino`
- Touch: `Adafruit CST8XX Library`
- IO expander: `Adafruit PCF8574`
- WiFi: `WiFi` from the ESP32 Arduino core
- UI: `lvgl`

Tap `Scan` to scan nearby WiFi APs. The list shows SSID, RSSI, and encryption state. Tap an AP to open the password panel, then tap `Connect` to start the connection attempt.

## Implementation

WiFi scanning and connection use the standard ESP32 Arduino `WiFi.h` APIs. No custom WiFi manager stack is implemented.

The ONX2432G028 display is 240 pixels wide, so this example constrains the UI for the 2.8-inch screen:

- The `WiFi Test` title is aligned to the left, leaving the top-right area for the `Scan` button.
- The status label is limited to 216 pixels and uses word wrapping.
- The WiFi list is limited to 216 pixels and each row is left-aligned.
- Long SSIDs are truncated from the right so the first characters remain visible.
- The connection panel, password field, and LVGL keyboard stay inside the screen bounds.

Display direction matches `01_touch_test`:

```cpp
#define DISPLAY_SWAP_XY false
#define DISPLAY_MIRROR_X true
#define DISPLAY_MIRROR_Y false
```

## Operation Flow

1. Power on and enter the WiFi Test page.
2. Tap `Scan` in the top-right corner. The sketch switches to STA mode and scans nearby APs.
3. The list shows up to 20 APs. Each item includes SSID, RSSI, and `open` / `secure` state.
4. Tap an AP to open the password panel.
5. Tap the password field to show LVGL's built-in keyboard.
6. Enter the password and tap `Connect` to start connecting.
7. When connected, the status label shows the SSID and IP address. Failed or disconnected states are also shown.

## Notes

- This example demonstrates scanning and basic connection only; WiFi credentials are not saved.
- For open networks, tap the AP and then tap `Connect` with an empty password field.
- The sketch calls `WiFi.disconnect(true)` before scanning so scan results and connection state are refreshed.
- When modifying the UI later, avoid fixed widths of 240 px or more. Use around 216 px for text and enable wrapping or ellipsis.

## Arduino IDE Settings

When opening this example in Arduino IDE, use:

- Board: `ESP32S3 Dev Module`
- Flash Size: `16MB (128Mb)`
- PSRAM: `OPI PSRAM`
- Partition Scheme: `16M Flash (3MB APP/9.9MB FATFS)`

## Files

- `05_wifi_test.ino`: Main Arduino sketch.
- `BoardConfig.h`: Board pins, resolution, touch, and LCD configuration.
- `build_opt.h`: LVGL build option; it currently skips the default `lv_conf.h`.
- `sketch.yaml`: Target setting record for ESP32S3R8 + 16 MB flash.

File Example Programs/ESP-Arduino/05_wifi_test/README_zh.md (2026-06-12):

# ESP32-S3 Arduino WiFi 测试示例

## 概述

本示例是 `05_wifi_test` 的 ESP-Arduino 版本，用于测试 WiFi 扫描和基础连接 UI。

使用的库：

- LCD：`GFX Library for Arduino`
- 触摸：`Adafruit CST8XX Library`
- IO 扩展：`Adafruit PCF8574`
- WiFi：ESP32 Arduino core 的 `WiFi`
- UI：`lvgl`

点击 `Scan` 按钮后，程序会扫描附近 WiFi AP，并显示 SSID、RSSI 和加密状态。点击某个 AP 后会弹出密码输入框，输入密码并点击 `Connect` 可尝试连接。

## 说明

WiFi 扫描和连接使用 ESP32 Arduino core 的标准 `WiFi.h`，没有自写 WiFi 管理栈。

ONX2432G028 屏幕宽度为 240 像素，本例程已按 2.8 寸屏幕重新约束 UI 尺寸：

- `WiFi Test` 标题靠左显示，右上角保留 `Scan` 按钮，避免两者重叠。
- 状态文字宽度限制为 216 像素，并启用自动换行。
- WiFi 列表宽度限制为 216 像素，列表项左对齐显示。
- SSID 过长时从右侧省略，避免左侧字符被裁掉。
- 连接面板、密码输入框和 LVGL 键盘均限制在屏幕边界内。

屏幕方向与 `01_touch_test` 一致：

```cpp
#define DISPLAY_SWAP_XY false
#define DISPLAY_MIRROR_X true
#define DISPLAY_MIRROR_Y false
```

## 操作流程

1. 上电后进入 WiFi Test 页面。
2. 点击右上角 `Scan`，程序切换到 STA 模式并扫描附近 AP。
3. 列表最多显示 20 个 AP，每一项包含 SSID、RSSI 和 `open` / `secure` 状态。
4. 点击 AP 后弹出密码输入面板。
5. 点击密码输入框会显示 LVGL 内置键盘。
6. 输入密码并点击 `Connect` 后开始连接。
7. 连接成功时显示当前 SSID 和 IP 地址；连接失败或断开时显示对应状态。

## 注意事项

- 本例程只演示扫描和基础连接，不保存 WiFi 配置。
- 开放网络可直接点击 AP 后点击 `Connect`，密码框可以留空。
- 扫描前会调用 `WiFi.disconnect(true)`，用于刷新扫描结果和连接状态。
- 后续修改 UI 时，不要使用超过 240 像素的固定宽度；文本建议使用 216 像素宽并开启换行或省略号。

## Arduino IDE 设置

使用 Arduino IDE 打开本例程时，开发板建议选择：

- Board: `ESP32S3 Dev Module`
- Flash Size: `16MB (128Mb)`
- PSRAM: `OPI PSRAM`
- Partition Scheme: `16M Flash (3MB APP/9.9MB FATFS)`

## 文件

- `05_wifi_test.ino`: Arduino 主程序。
- `BoardConfig.h`: 板级引脚、分辨率和触摸/LCD 配置。
- `build_opt.h`: LVGL 编译选项，当前仅跳过默认 `lv_conf.h`。
- `sketch.yaml`: 记录 ESP32S3R8 + 16MB Flash 的目标配置。

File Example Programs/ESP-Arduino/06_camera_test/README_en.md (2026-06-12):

# ESP32-S3 Arduino Camera Test Example

## Overview

This is the ESP-Arduino version of `06_camera_test`. It tests camera capture and live LCD preview on the ONX2432G028 board.

Libraries used:

- LCD: `GFX Library for Arduino`
- Touch: `Adafruit CST8XX Library`
- IO expander: `Adafruit PCF8574`
- UI: `lvgl`
- Camera: `esp_camera` from the ESP32 Arduino core

## Features

- ST7789U display through Arduino_GFX.
- CST826 touch through Adafruit CST8XX.
- LVGL title and status label.
- RGB565/HVGA camera capture through the ESP32 Arduino core camera driver.
- Camera frames are scaled to 240x160 and pushed directly to the LCD preview area with Arduino_GFX to reduce per-frame copies.

## Runtime Flow

1. Initialize I2C, PCF8574, LCD, backlight, and touch.
2. Pull camera `PWDN` low through PCF8574 to wake the camera module. The sketch releases both ONX2432G028 CAM_PWDN pin 4 and the pin 3 path used by the verified 3.5-inch camera example, so the same camera module/adapter can be detected.
3. Initialize `esp_camera` with HVGA `480x320` and `RGB565` output.
4. Draw the `Camera Test` title and status text with LVGL.
5. In the main loop, capture one frame about every 80 ms, scale it to `240x160`, and draw it in the middle of the screen.

## Camera Configuration

- Frame size: `FRAMESIZE_HVGA`
- Resolution: `480x320`
- Pixel format: `PIXFORMAT_RGB565`
- XCLK: `20 MHz`
- Frame buffers: two frame buffers in PSRAM.
- Preview: scaled to `240x160` so it stays inside the ONX2432G028 240-pixel screen width.

Initialization follows the ONX2432G028 ESP-IDF `06_camera_test` first:

1. First try the ESP-IDF SCCB configuration: `pin_sccb_sda=-1`, `pin_sccb_scl=-1`, `sccb_i2c_port=0`, reusing I2C0.
2. If the Arduino camera driver fails in that mode, fall back to direct GPIO8/GPIO7 SCCB pins.
3. The serial log prints each initialization attempt and error code for hardware/debug checks.

## Display And Size

- Display direction matches `01_touch_test`: `DISPLAY_SWAP_XY=false`, `DISPLAY_MIRROR_X=true`, `DISPLAY_MIRROR_Y=false`.
- The status label is limited to 216 pixels and uses word wrapping.
- Preview scaling is line-based and only allocates one temporary 240-pixel line buffer.

This example matches the ESP-IDF behavior: after boot, it continuously displays the camera preview and does not provide a pause/resume button.

## Arduino IDE Settings

When opening this example in Arduino IDE, use:

- Board: `ESP32S3 Dev Module`
- Flash Size: `16MB (128Mb)`
- PSRAM: `OPI PSRAM`
- Partition Scheme: `16M Flash (3MB APP/9.9MB FATFS)`

## Files

- `06_camera_test.ino`: Main Arduino sketch.
- `BoardConfig.h`: LCD, touch, PCF8574, and camera pin configuration.
- `build_opt.h`: LVGL build option; it currently skips the default `lv_conf.h`.
- `sketch.yaml`: Target setting record for ESP32S3R8 + 16 MB flash.

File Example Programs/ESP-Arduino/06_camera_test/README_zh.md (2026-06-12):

# ESP32-S3 Arduino 摄像头测试示例

## 概述

本示例是 `06_camera_test` 的 ESP-Arduino 版本，用于测试 ONX2432G028 的摄像头采集和 LCD 实时预览。

使用的库：

- LCD：`GFX Library for Arduino`
- 触摸：`Adafruit CST8XX Library`
- IO 扩展：`Adafruit PCF8574`
- UI：`lvgl`
- 摄像头：ESP32 Arduino core 自带 `esp_camera`

## 功能

- 使用 Arduino_GFX 驱动 ST7789U LCD。
- 使用 Adafruit CST8XX 读取 CST826 触摸。
- 使用 LVGL 绘制标题和状态提示。
- 使用 ESP32 Arduino core 自带的 `esp_camera` 获取 RGB565/HVGA 图像。
- 摄像头帧按宽度缩放为 240x160 后，通过 Arduino_GFX 直接刷新到屏幕预览区域，减少每帧复制。

## 运行流程

1. 初始化 I2C、PCF8574、LCD、背光和触摸。
2. 通过 PCF8574 拉低摄像头 `PWDN`，唤醒摄像头模组。当前会同时释放 ONX2432G028 的 CAM_PWDN pin 4 和 3.5 寸已验证路径使用的 pin 3，以兼容同款摄像头/转接方式。
3. 初始化 `esp_camera`，配置为 HVGA `480x320`、`RGB565` 输出。
4. 使用 LVGL 绘制 `Camera Test` 标题和状态文本。
5. 主循环中约每 80 ms 获取一帧摄像头图像，缩放为 `240x160` 后显示在屏幕中部。

## 摄像头配置

- 帧尺寸：`FRAMESIZE_HVGA`
- 分辨率：`480x320`
- 像素格式：`PIXFORMAT_RGB565`
- XCLK：`20 MHz`
- 帧缓冲：PSRAM 中 2 个 frame buffer。
- 预览显示：缩放到 `240x160`，避免超出 ONX2432G028 的 240 像素屏幕宽度。

初始化策略优先参考 ONX2432G028 ESP-IDF `06_camera_test`：

1. 第一轮使用 ESP-IDF SCCB 配置：`pin_sccb_sda=-1`、`pin_sccb_scl=-1`、`sccb_i2c_port=0`，复用 I2C0。
2. 如果 Arduino camera 驱动在该模式下初始化失败，则回退为直接使用 GPIO8/GPIO7 作为 SCCB。
3. 串口会打印每轮初始化尝试和错误码，方便定位硬件或连接问题。

## 显示与尺寸

- 屏幕方向与 `01_touch_test` 保持一致：`DISPLAY_SWAP_XY=false`、`DISPLAY_MIRROR_X=true`、`DISPLAY_MIRROR_Y=false`。
- 状态文字宽度限制为 216 像素并启用自动换行。
- 摄像头画面使用逐行缩放，只额外占用一行 240 像素的临时缓冲。

本例程行为与 ESP-IDF 版本保持一致：上电后持续显示摄像头预览，不提供暂停/恢复按钮。

## Arduino IDE 设置

使用 Arduino IDE 打开本例程时，开发板建议选择：

- Board: `ESP32S3 Dev Module`
- Flash Size: `16MB (128Mb)`
- PSRAM: `OPI PSRAM`
- Partition Scheme: `16M Flash (3MB APP/9.9MB FATFS)`

## 文件

- `06_camera_test.ino`: Arduino 主程序。
- `BoardConfig.h`: LCD、触摸、PCF8574 和摄像头引脚配置。
- `build_opt.h`: LVGL 编译选项，当前仅跳过默认 `lv_conf.h`。
- `sketch.yaml`: 记录 ESP32S3R8 + 16MB Flash 的目标配置。

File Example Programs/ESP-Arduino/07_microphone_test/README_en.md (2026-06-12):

# ESP32-S3 Arduino Microphone Record/Playback Example

## Overview

This is the ESP-Arduino version of `07_microphone_test`. It tests PDM microphone recording and speaker playback on the ONX2432G028 board.

The interaction matches the ESP-IDF example: press and hold `MIC` to record, release it to loop-play the audio stored in RAM, and tap `Stop` to stop recording or playback.

Libraries used:

- LCD: `GFX Library for Arduino`
- Touch: `Adafruit CST8XX Library`
- IO expander: `Adafruit PCF8574`
- UI: `lvgl`
- Microphone: ESP-IDF `driver/i2s_pdm.h` from the ESP32 Arduino core
- Speaker: ESP-IDF `driver/i2s_std.h` from the ESP32 Arduino core

## Runtime Flow

1. Initialize LCD, CST826 touch, PCF8574, and PDM microphone input.
2. Allocate a 30-second recording buffer from PSRAM.
3. Press and hold `MIC`: recording starts and the button turns red.
4. Release `MIC`: recording stops, speaker I2S output is opened lazily, and loop playback starts; the button turns green.
5. Tap `Stop`: stop recording or playback, mute the speaker amplifier first, then write silence and disable I2S output.

## Audio Configuration

- Sample rate: `16000 Hz`
- Bit depth: `16-bit`
- Recording format: PDM RX converted to PCM mono
- Playback format: I2S STD TX mono
- Maximum record time: `30 s`
- Record buffer: PSRAM first, internal RAM fallback

Note: the ESP-IDF version includes the ESP-SR/AFE processing chain. The Arduino version keeps the core record/playback behavior and uses the standard I2S drivers bundled with the ESP32 Arduino core instead of porting ESP-SR/AFE.

## Speaker Mute Handling

The ONX2432G028 speaker amplifier enable pin is connected to `I2S_CTRL` on the PCF8574. This example uses the same mute strategy as the music example to avoid the boot pop and the idle hiss after stopping playback:

- The PCF8574 shadow byte keeps `I2S_CTRL` low by default.
- PCF8574 is initialized first at `100 kHz`, and the safe output state is written before LCD reset.
- `setup()` does not initialize speaker I2S TX, because switching BCLK/WS/DOUT into I2S peripheral mode at boot caused an audible transient on this board.
- Playback initializes and enables I2S TX only when needed, writes a short silence lead-in, then enables the speaker amplifier.
- `Stop` mutes the speaker amplifier first, then writes silence and disables I2S TX.

## Display Direction

The display direction macros match the other 2.8-inch examples:

```cpp
#define DISPLAY_SWAP_XY false
#define DISPLAY_MIRROR_X true
#define DISPLAY_MIRROR_Y false
```

The status label is limited to `216 px` and uses wrapping so messages stay inside the 240x320 screen.

## Arduino IDE Settings

When opening this example in Arduino IDE, use:

- Board: `ESP32S3 Dev Module`
- Flash Size: `16MB (128Mb)`
- PSRAM: `OPI PSRAM`
- Partition Scheme: `16M Flash (3MB APP/9.9MB FATFS)`

## Files

- `07_microphone_test.ino`: Main Arduino sketch.
- `BoardConfig.h`: LCD, touch, PDM microphone, I2S speaker, and PCF8574 pin configuration.
- `build_opt.h`: LVGL build option; it currently skips the default `lv_conf.h`.
- `sketch.yaml`: Arduino CLI profile with the 16MB Flash, OPI PSRAM, and partition settings.

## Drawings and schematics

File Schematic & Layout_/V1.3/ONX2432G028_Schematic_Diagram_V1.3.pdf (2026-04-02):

# 0.75PF².2NH

# SD CARD

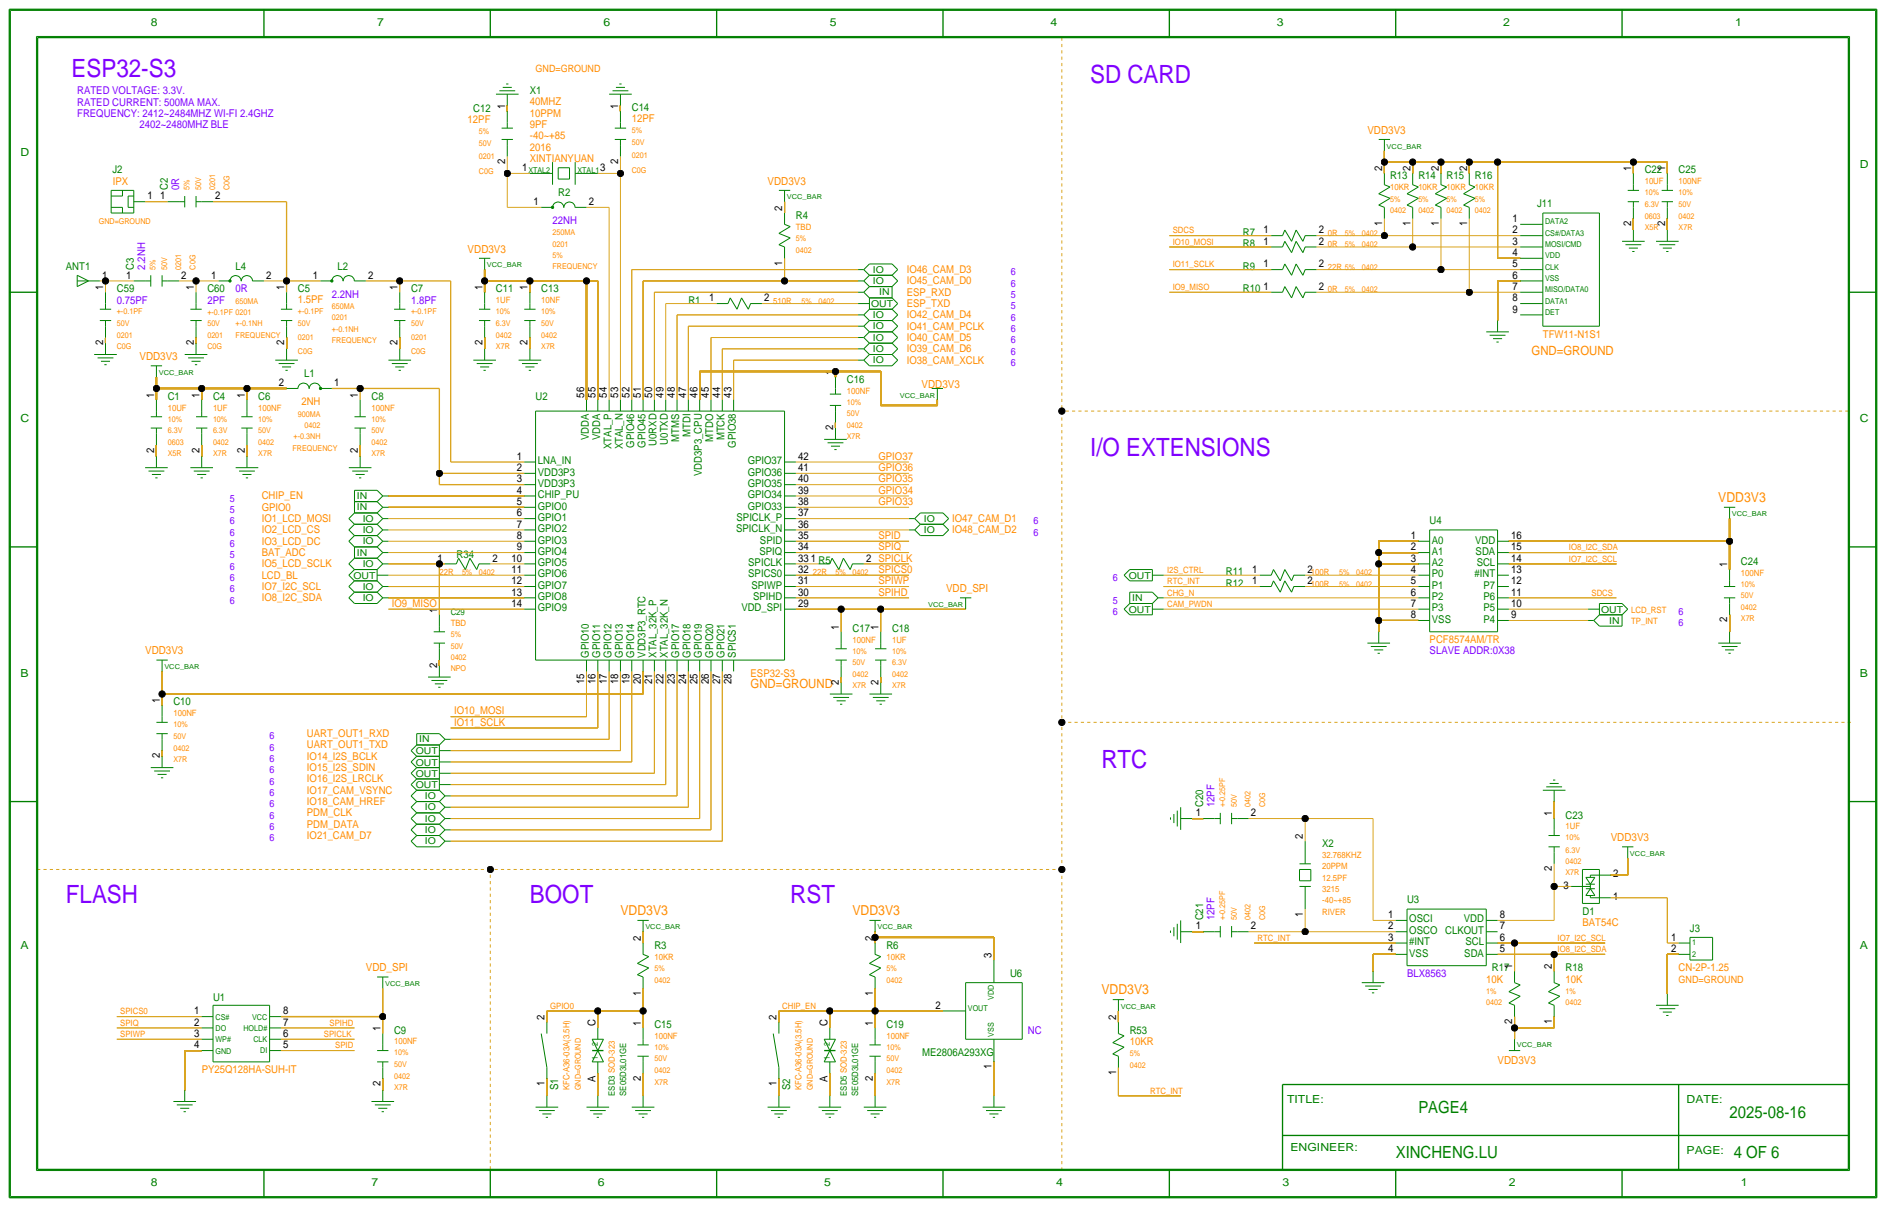
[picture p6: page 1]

TITLE: TITLE: PAGE4 PAGE4 | DATE: DATE: 2025-08-16 2025-08-16

ENGINEER: XINCHENG.LU | PAGE:

# USB TO TTL / UART INPUT

# POWER ON

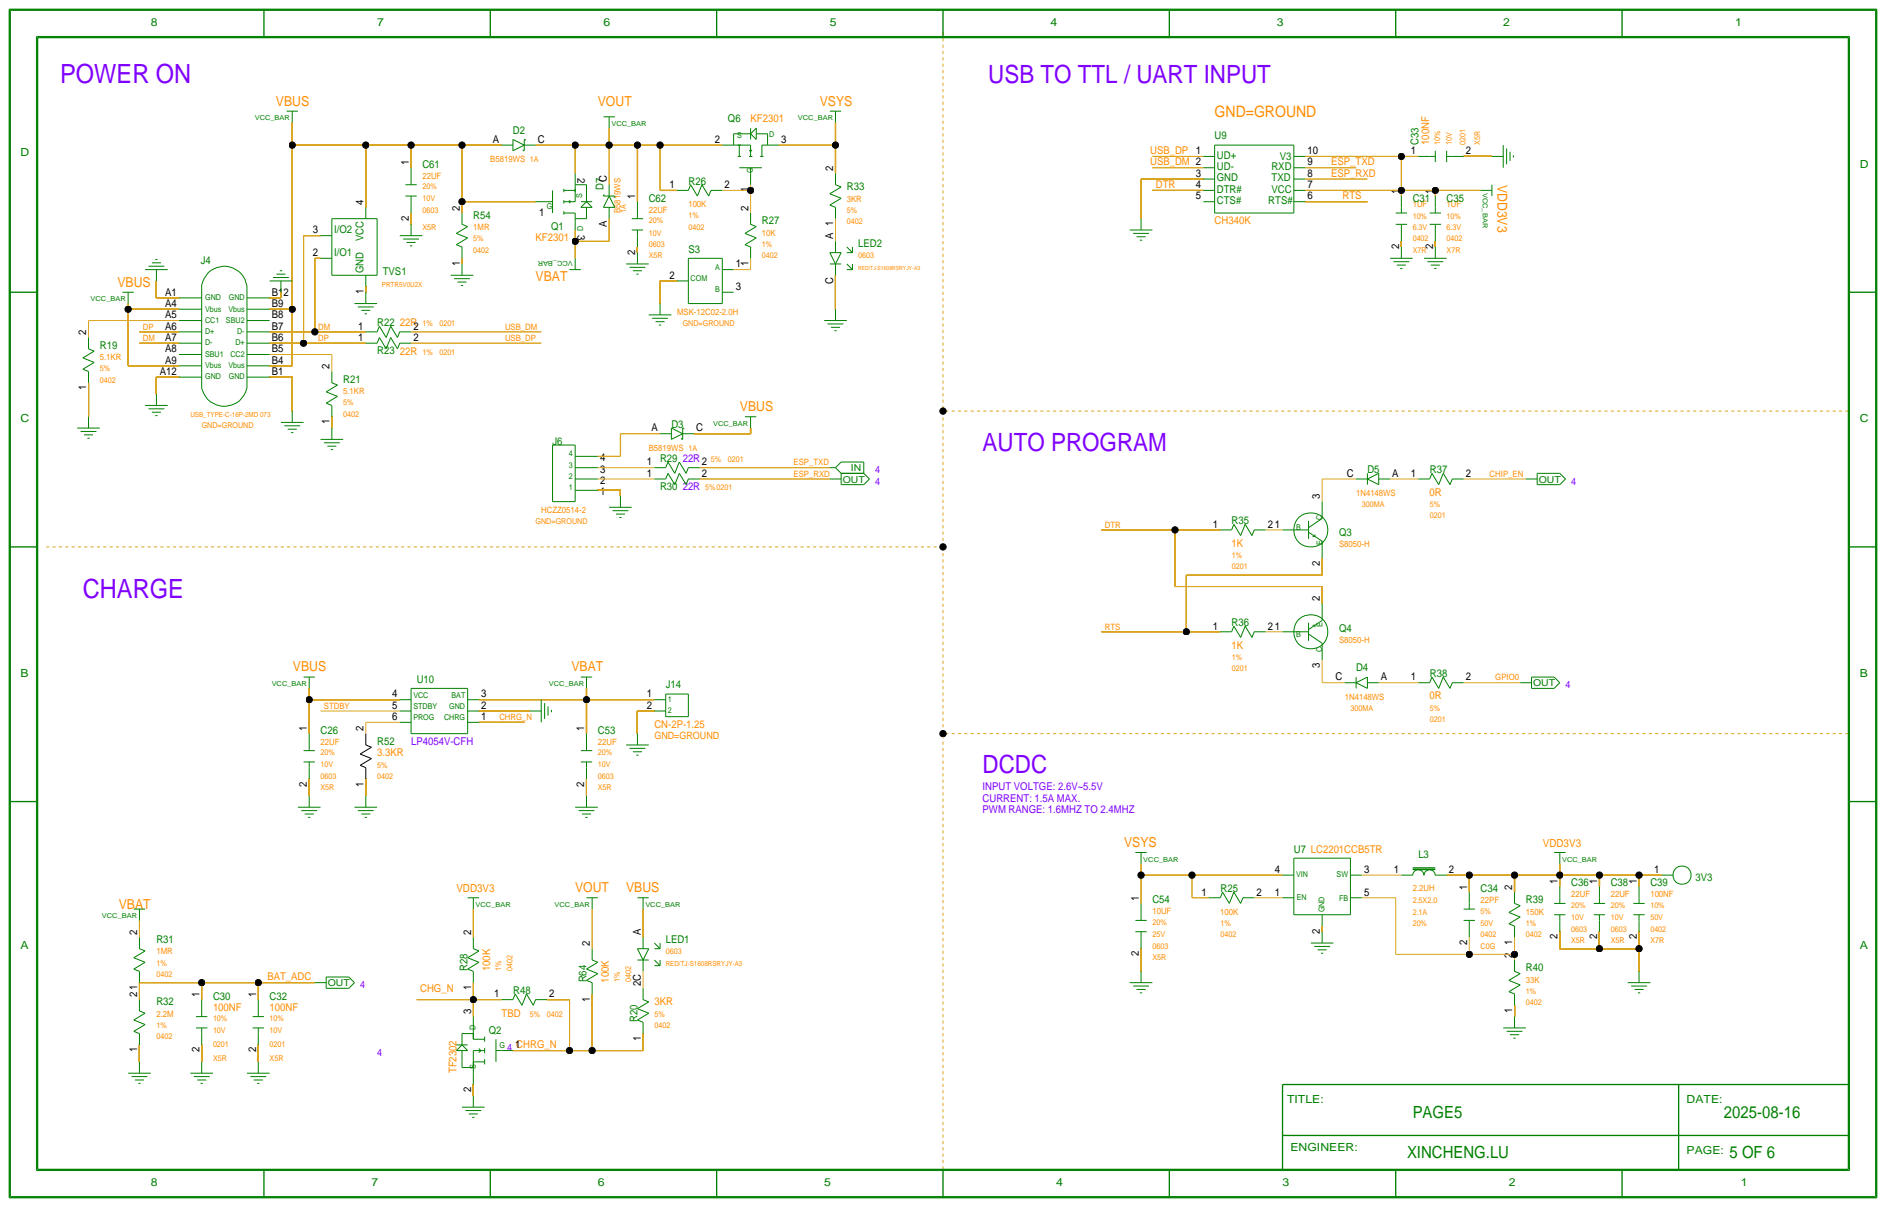
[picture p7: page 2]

USB TO TTL / UART INPUT

# LCD

# CAMERA

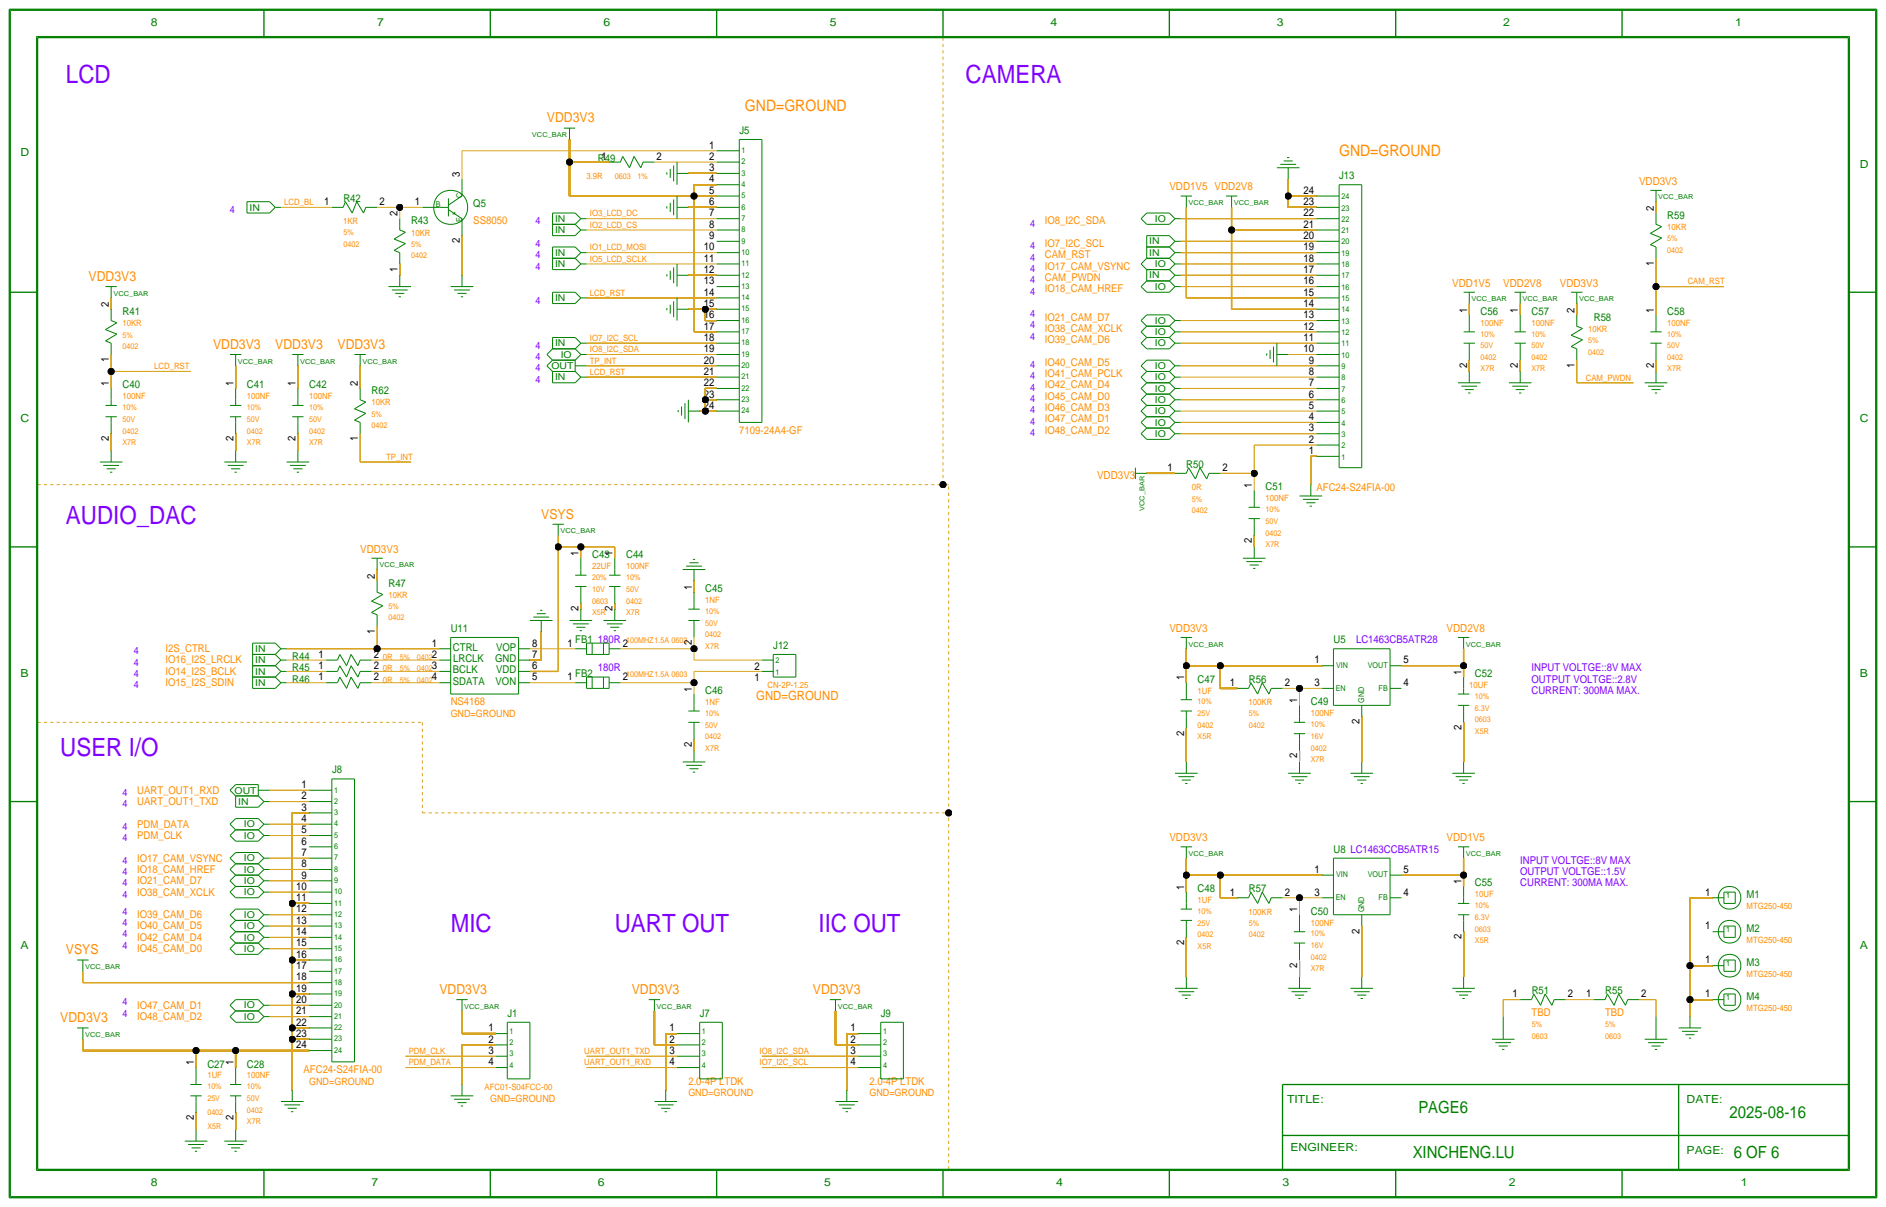
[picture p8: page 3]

VDD3V3

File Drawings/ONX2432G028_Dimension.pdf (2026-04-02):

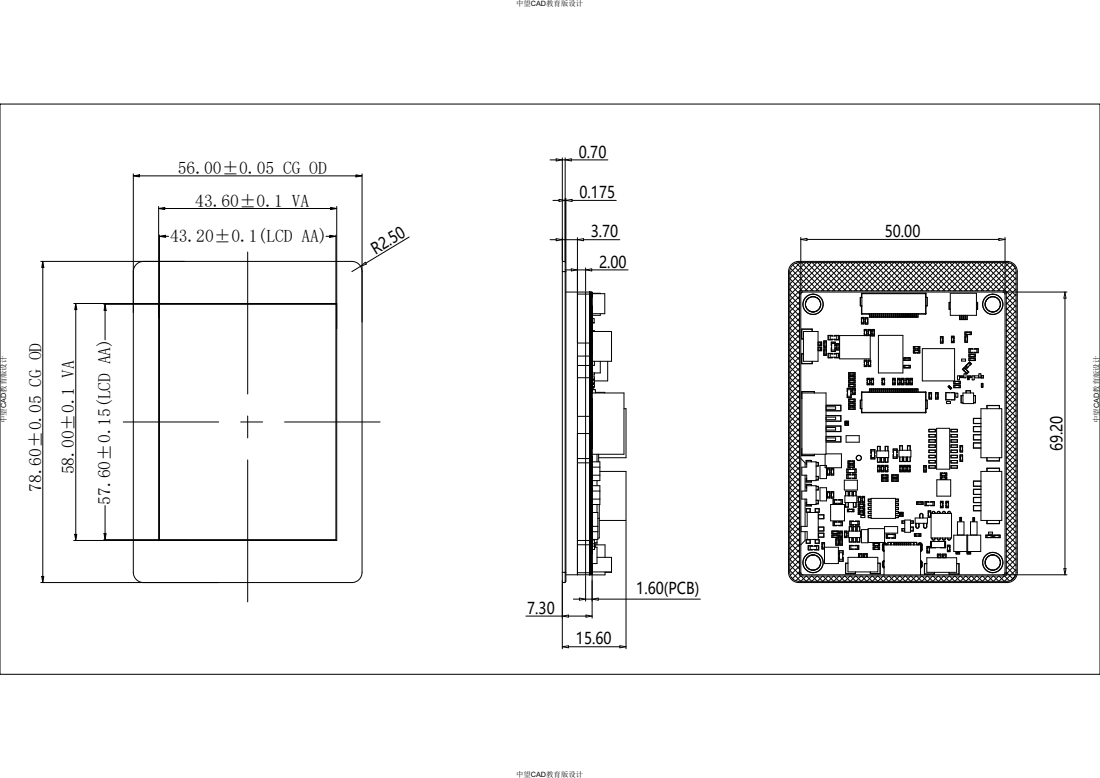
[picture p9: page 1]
43.20±0.1(LCD AA); 57.60±0.15(LCD AA); 1.60(PCB); 中望CAD教育版设计

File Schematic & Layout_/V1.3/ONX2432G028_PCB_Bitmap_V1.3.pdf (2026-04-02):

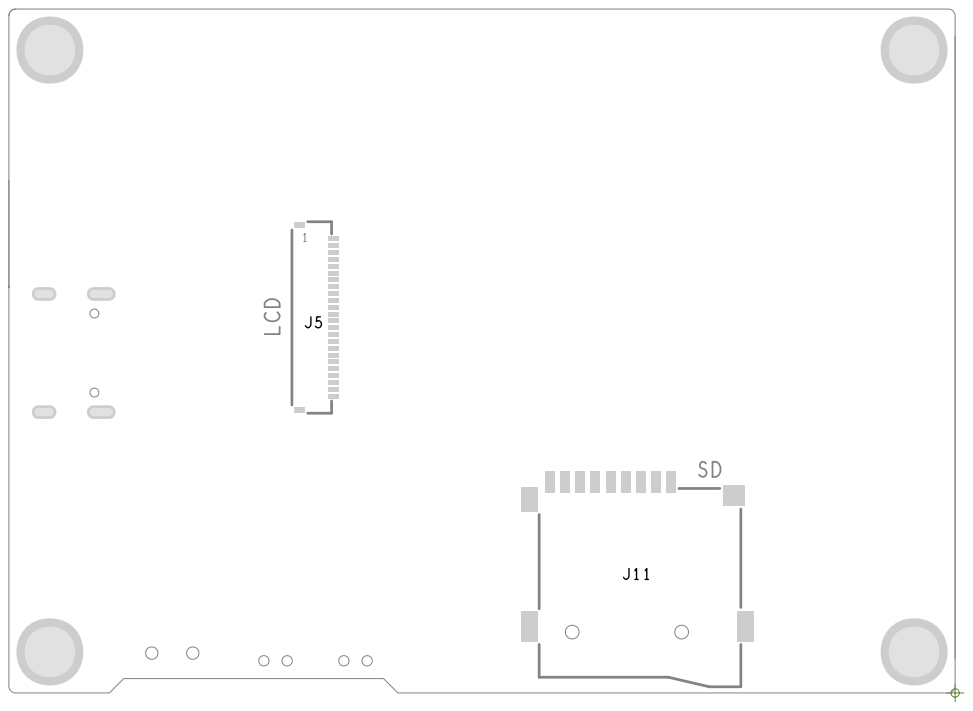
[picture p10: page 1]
LCD

## CLK

3V3

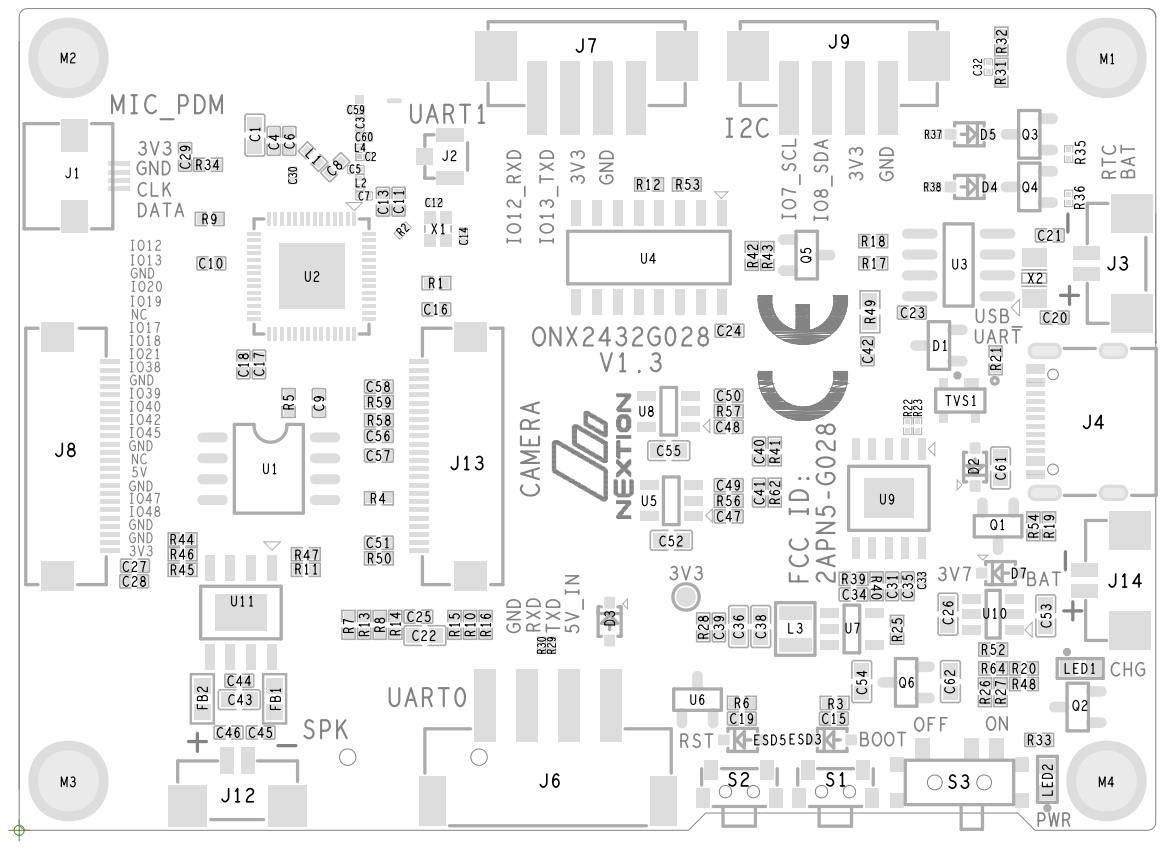
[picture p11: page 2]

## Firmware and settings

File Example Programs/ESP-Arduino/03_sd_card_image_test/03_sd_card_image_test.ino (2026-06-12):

#include <Arduino.h>
#include <Wire.h>
#include <SPI.h>
#include <SD_MMC.h>
#include <FS.h>
#include <Arduino_GFX_Library.h>
#include <Adafruit_CST8XX.h>
#include <Adafruit_PCF8574.h>
#include <jpeg_decoder.h>

#define LV_CONF_SKIP
#include <lvgl.h>
// Reuse LVGL's bundled lodepng implementation for PNG decoding. The Arduino
// sketch calls the C API directly, so the C++ wrappers are disabled here.
#define LODEPNG_NO_COMPILE_CPP
extern "C" {
#include <extra/libs/png/lodepng.h>
}

#include "BoardConfig.h"

static const uint32_t LCD_SPI_FREQ = 40000000;
static const uint16_t LVGL_BUF_LINES = 40;
static const char *IMAGE_DIR = "/images";
static const uint8_t MAX_IMAGES = 64;

// Keep the same direction macros as the touch example so the LCD and CST826
// coordinate systems stay aligned across demos.
#define DISPLAY_SWAP_XY false
#define DISPLAY_MIRROR_X true
#define DISPLAY_MIRROR_Y false

Arduino_DataBus *bus = new Arduino_HWSPI(
    LCD_DC_PIN, LCD_CS_PIN, LCD_SCLK_PIN, LCD_MOSI_PIN, LCD_MISO_PIN, &SPI, true);
Arduino_GFX *gfx = new Arduino_ST7789(bus, GFX_NOT_DEFINED, 0, false, LCD_H_RES, LCD_V_RES);

Adafruit_CST8XX touch;
Adafruit_PCF8574 ioExpander;

static lv_disp_draw_buf_t drawBuf;
static lv_disp_drv_t dispDrv;
static lv_color_t dispBuf[LCD_H_RES * LVGL_BUF_LINES];
static String images[MAX_IMAGES];
static uint8_t imageCount = 0;
static int imageIndex = 0;
static bool sdReady = false;
static bool imageBrowserMode = false;
static bool imageNeedsRedraw = false;

// Full-screen image pages are rendered into PSRAM first, then pushed to LCD in
// bands. This avoids showing top-to-bottom decode progress on the panel.
static uint16_t *frameBuf = nullptr;

static uint8_t displayRotationFromConfig() {
  bool gfxMirrorX = !DISPLAY_MIRROR_X;
  bool gfxMirrorY = DISPLAY_MIRROR_Y;
  if (!DISPLAY_SWAP_XY && !gfxMirrorX && !gfxMirrorY) return 0;
  if (DISPLAY_SWAP_XY && gfxMirrorX && !gfxMirrorY) return 1;
  if (!DISPLAY_SWAP_XY && gfxMirrorX && gfxMirrorY) return 2;
  if (DISPLAY_SWAP_XY && !gfxMirrorX && gfxMirrorY) return 3;
  if (!DISPLAY_SWAP_XY && gfxMirrorX && !gfxMirrorY) return 4;
  if (DISPLAY_SWAP_XY && gfxMirrorX && gfxMirrorY) return 5;
  if (!DISPLAY_SWAP_XY && !gfxMirrorX && gfxMirrorY) return 6;
  return 7;
}

static void setExpanderPin(uint8_t pin, bool level) {
  static uint8_t state = 0xFF;
  if (level) state |= (1 << pin);
  else state &= ~(1 << pin);
  ioExpander.digitalWriteByte(state);
}

static void lcdResetByExpander() {
  if (!ioExpander.begin(PCF8574_ADDR, &Wire)) {
    Serial.println("PCF8574 init failed");
    return;
  }
  // Keep all expander outputs high except the pins we actively drive below.
  ioExpander.digitalWriteByte(0xFF);
  delay(20);
  setExpanderPin(PCF8574_PIN_LCD_RST, false);
  delay(120);
  setExpanderPin(PCF8574_PIN_LCD_RST, true);
  delay(120);
}

static void lvglFlush(lv_disp_drv_t *drv, const lv_area_t *area, lv_color_t *colorP) {
  uint32_t width = area->x2 - area->x1 + 1;
  uint32_t height = area->y2 - area->y1 + 1;
#if (LV_COLOR_16_SWAP != 0)
  gfx->draw16bitBeRGBBitmap(area->x1, area->y1, (uint16_t *)&colorP->full, width, height);
#else
  gfx->draw16bitRGBBitmap(area->x1, area->y1, (uint16_t *)&colorP->full, width, height);
#endif
  lv_disp_flush_ready(drv);
}

static void lvglTouchRead(lv_indev_drv_t *, lv_indev_data_t *data) {
  static int16_t lastX = 0;
  static int16_t lastY = 0;
  if (touch.touched()) {
    CST_TS_Point point = touch.getPoint();
    lastX = constrain(point.x, 0, (int16_t)gfx->width() - 1);
    lastY = constrain(point.y, 0, (int16_t)gfx->height() - 1);
    data->state = LV_INDEV_STATE_PR;
  } else {
    data->state = LV_INDEV_STATE_REL;
  }
  data->point.x = lastX;
  data->point.y = lastY;
}

static void lvglBegin() {
  // LVGL is still used for the no-card / no-image prompt pages. The image
  // browser draws directly to the LCD after a full frame has been decoded.
  lv_init();
  lv_disp_draw_buf_init(&drawBuf, dispBuf, nullptr, LCD_H_RES * LVGL_BUF_LINES);
  lv_disp_drv_init(&dispDrv);
  dispDrv.hor_res = gfx->width();
  dispDrv.ver_res = gfx->height();
  dispDrv.flush_cb = lvglFlush;
  dispDrv.draw_buf = &drawBuf;
  lv_disp_drv_register(&dispDrv);
  static lv_indev_drv_t indevDrv;
  lv_indev_drv_init(&indevDrv);
  indevDrv.type = LV_INDEV_TYPE_POINTER;
  indevDrv.read_cb = lvglTouchRead;
  lv_indev_drv_register(&indevDrv);
}

static void boardBegin() {
  Serial.begin(115200);
  delay(500);
  Serial.println("\nONX2432G028 Arduino 03_sd_card_image_test");
  Wire.begin(NEXTION_IIC_SDA_PIN, NEXTION_IIC_SCL_PIN, 400000);
  lcdResetByExpander();
  gfx->begin(LCD_SPI_FREQ);
  gfx->setRotation(displayRotationFromConfig());
  gfx->fillScreen(RGB565_WHITE);
  pinMode(LCD_BL_PIN, OUTPUT);
  digitalWrite(LCD_BL_PIN, HIGH);
  touch.begin(&Wire, CST826_ADDR);
  lvglBegin();
}

static bool mountSdCard() {
  setExpanderPin(PCF8574_PIN_SDCS, true);
  SD_MMC.setPins(SD_CLK_PIN, SD_CMD_PIN, SD_D0_PIN);
  sdReady = SD_MMC.begin("/sdcard", true, false, SDMMC_FREQ_DEFAULT);
  return sdReady;
}

static bool endsWithIgnoreCase(const String &value, const char *suffix) {
  String lower = value;
  lower.toLowerCase();
  return lower.endsWith(suffix);
}

static bool isImageFile(const String &name) {
  // Keep the scan rule close to the ESP-IDF demo. Some extensions are listed
  // for directory compatibility, although this Arduino port renders JPG/PNG.
  return endsWithIgnoreCase(name, ".jpg") || endsWithIgnoreCase(name, ".jpeg") ||
         endsWithIgnoreCase(name, ".png") || endsWithIgnoreCase(name, ".bmp") ||
         endsWithIgnoreCase(name, ".bin") || endsWithIgnoreCase(name, ".qoi") ||
         endsWithIgnoreCase(name, ".sjpg") || endsWithIgnoreCase(name, ".spng") ||
         endsWithIgnoreCase(name, ".sqoi");
}

static String baseNameOf(const char *path) {
  String name(path);
  int slash = name.lastIndexOf('/');
  if (slash >= 0) name = name.substring(slash + 1);
  return name;
}

static String imagePathAt(int index) {
  return String(IMAGE_DIR) + "/" + images[index];
}

static void sortImages() {
  // Stable visual order makes swipe testing repeatable regardless of FAT entry
  // order on the SD card.
  for (uint8_t i = 0; i + 1 < imageCount; ++i) {
    for (uint8_t j = i + 1; j < imageCount; ++j) {
      String a = images[i];
      String b = images[j];
      a.toLowerCase();
      b.toLowerCase();
      if (a > b) {
        String tmp = images[i];
        images[i] = images[j];
        images[j] = tmp;
      }
    }
  }
}

static bool isJpegFile(const String &name) {
  return endsWithIgnoreCase(name, ".jpg") || endsWithIgnoreCase(name, ".jpeg") ||
         endsWithIgnoreCase(name, ".sjpg");
}

static bool isPngFile(const String &name) {
  return endsWithIgnoreCase(name, ".png") || endsWithIgnoreCase(name, ".spng");
}

static void showCenteredMessage(const char *message, uint32_t color = RGB565_RED) {
  // Direct-draw error pages are used after LVGL is suspended for image browsing.
  // Wrap text manually so long messages still fit on the 240 px wide panel.
  static const uint8_t TEXT_SIZE = 2;
  static const uint8_t CHAR_W = 6 * TEXT_SIZE;
  static const uint8_t LINE_H = 8 * TEXT_SIZE + 4;
  int16_t maxChars = max<int16_t>(1, (gfx->width() - 24) / CHAR_W);
  String lines[4];
  uint8_t lineCount = 0;
  String word;
  const char *p = message;
  while (*p && lineCount < 4) {
    if (*p == ' ' || *(p + 1) == '\0') {
      if (*(p + 1) == '\0' && *p != ' ') word += *p;
      if (lines[lineCount].length() == 0) {
        lines[lineCount] = word;
      } else if ((int)(lines[lineCount].length() + 1 + word.length()) <= maxChars) {
        lines[lineCount] += " ";
        lines[lineCount] += word;
      } else if (lineCount < 3) {
        lineCount++;
        lines[lineCount] = word;
      }
      word = "";
    } else {
      word += *p;
    }
    p++;
  }
  if (lineCount == 0 && lines[0].length() == 0) lines[0] = message;
  lineCount++;

  gfx->fillScreen(RGB565_WHITE);
  gfx->setTextColor(color);
  gfx->setTextSize(TEXT_SIZE);
  int16_t y = (gfx->height() - lineCount * LINE_H) / 2;
  for (uint8_t i = 0; i < lineCount; ++i) {
    int16_t x = (gfx->width() - lines[i].length() * CHAR_W) / 2;
    gfx->setCursor(max<int16_t>(0, x), y + i * LINE_H);
    gfx->print(lines[i]);
  }
}

static void showLvglPrompt(lv_obj_t *scr, const char *message) {
  // All initial abnormal pages share the same geometry. Keep the label narrower
  // than the 240 px panel so LVGL can wrap English text without clipping.
  lv_obj_set_style_bg_color(scr, lv_color_white(), 0);
  lv_obj_t *label = lv_label_create(scr);
  lv_obj_set_width(label, gfx->width() - 24);
  lv_label_set_long_mode(label, LV_LABEL_LONG_WRAP);
  lv_obj_set_style_text_align(label, LV_TEXT_ALIGN_CENTER, 0);
  lv_obj_set_style_text_color(label, lv_color_hex(0xff0000), 0);
  lv_label_set_text(label, message);
  lv_obj_align(label, LV_ALIGN_CENTER, 0, 0);
}

static bool ensureFrameBuffer() {
  if (frameBuf) return true;
  frameBuf = static_cast<uint16_t *>(ps_malloc(gfx->width() * gfx->height() * sizeof(uint16_t)));
  if (!frameBuf) {
    Serial.println("Frame buffer allocation failed");
    return false;
  }
  return true;
}

static void clearFrameBuffer(uint16_t color) {
  if (!frameBuf) return;
  uint32_t pixels = gfx->width() * gfx->height();
  for (uint32_t i = 0; i < pixels; ++i) {
    frameBuf[i] = color;
  }
}

static void presentFrameBuffer() {
  if (!frameBuf) return;
  // Arduino_GFX transfers are split into moderate bands to keep SPI writes
  // stable while still updating the finished frame quickly.
  const int16_t linesPerFlush = 40;
  for (int16_t y = 0; y < gfx->height(); y += linesPerFlush) {
    int16_t h = min<int16_t>(linesPerFlush, gfx->height() - y);
    gfx->draw16bitBeRGBBitmap(0, y, frameBuf + y * gfx->width(), gfx->width(), h);
  }
}

static uint16_t rgb565BigEndian(uint8_t r, uint8_t g, uint8_t b) {
  // draw16bitBeRGBBitmap expects RGB565 bytes in big-endian order.
  uint16_t rgb565 = ((uint16_t)(r & 0xF8) << 8) | ((uint16_t)(g & 0xFC) << 3) | (b >> 3);
  return (uint16_t)((rgb565 << 8) | (rgb565 >> 8));
}

static void drawScaledRgb565Be(const uint16_t *src, uint16_t srcW, uint16_t srcH) {
  if (!src || srcW == 0 || srcH == 0 || !frameBuf) return;

  // Match the verified behavior on hardware: scale every image to screen width
  // and center it vertically when the aspect ratio leaves unused space.
  uint16_t dstW = gfx->width();
  uint32_t scaledH32 = ((uint32_t)srcH * dstW + srcW / 2) / srcW;
  uint16_t dstH = min<uint32_t>(scaledH32, gfx->height());
  int16_t dstX = 0;
  int16_t dstY = (gfx->height() - dstH) / 2;

  for (uint16_t y = 0; y < dstH; ++y) {
    uint32_t srcY = ((uint32_t)y * srcH) / dstH;
    uint16_t *dst = frameBuf + (dstY + y) * gfx->width() + dstX;
    const uint16_t *srcRow = src + srcY * srcW;
    for (uint16_t x = 0; x < dstW; ++x) {
      uint32_t srcX = ((uint32_t)x * srcW) / dstW;
      dst[x] = srcRow[srcX];
    }
  }
}

static void drawScaledRgbaLvgl(const uint8_t *rgba, uint16_t srcW, uint16_t srcH) {
  if (!rgba || srcW == 0 || srcH == 0 || !frameBuf) return;

  // lodepng is compiled through LVGL on this target, whose 32-bit color layout
  // is BGRA in memory. Alpha is composited over the white screen background.
  uint16_t dstW = gfx->width();
  uint32_t scaledH32 = ((uint32_t)srcH * dstW + srcW / 2) / srcW;
  uint16_t dstH = min<uint32_t>(scaledH32, gfx->height());
  int16_t dstX = 0;
  int16_t dstY = (gfx->height() - dstH) / 2;

  for (uint16_t y = 0; y < dstH; ++y) {
    uint32_t srcY = ((uint32_t)y * srcH) / dstH;
    uint16_t *dst = frameBuf + (dstY + y) * gfx->width() + dstX;
    const uint8_t *srcRow = rgba + srcY * srcW * 4;
    for (uint16_t x = 0; x < dstW; ++x) {
      uint32_t srcX = ((uint32_t)x * srcW) / dstW;
      const uint8_t *px = srcRow + srcX * 4;

      uint8_t b = px[0];
      uint8_t g = px[1];
      uint8_t r = px[2];
      uint8_t a = px[3];
      if (a < 255) {
        r = ((uint16_t)r * a + 255U * (255U - a)) / 255U;
        g = ((uint16_t)g * a + 255U * (255U - a)) / 255U;
        b = ((uint16_t)b * a + 255U * (255U - a)) / 255U;
      }
      dst[x] = rgb565BigEndian(r, g, b);
    }
  }
}

static bool readWholeFile(const String &path, uint8_t **data, size_t *size) {
  *data = nullptr;
  *size = 0;

  File file = SD_MMC.open(path, FILE_READ);
  if (!file) return false;

  // Decode libraries expect contiguous input. Use PSRAM so larger images do not
  // consume the ESP32-S3 internal SRAM needed by LVGL and the SD stack.
  size_t fileSize = file.size();
  uint8_t *buffer = static_cast<uint8_t *>(ps_malloc(fileSize));
  if (!buffer) {
    file.close();
    return false;
  }

  size_t bytesRead = file.read(buffer, fileSize);
  file.close();
  if (bytesRead != fileSize) {
    free(buffer);
    return false;
  }

  *data = buffer;
  *size = fileSize;
  return true;
}

static bool drawJpegImage(const String &path) {
  uint8_t *jpegData = nullptr;
  size_t jpegSize = 0;
  if (!readWholeFile(path, &jpegData, &jpegSize)) return false;

  // Query the original dimensions first for logging and to size the decoder
  // output buffer correctly before the actual JPEG decode.
  esp_jpeg_image_cfg_t infoCfg = {};
  infoCfg.indata = jpegData;
  infoCfg.indata_size = jpegSize;
  infoCfg.out_format = JPEG_IMAGE_FORMAT_RGB565;
  infoCfg.out_scale = JPEG_IMAGE_SCALE_0;

  esp_jpeg_image_output_t originalInfo = {};
  esp_err_t err = esp_jpeg_get_image_info(&infoCfg, &originalInfo);
  if (err != ESP_OK) {
    Serial.printf("esp_jpeg_get_image_info failed: 0x%x\r\n", (unsigned)err);
    free(jpegData);
    return false;
  }

  // Decode at original resolution, then use one common scaler for JPEG and PNG.
  // This keeps same-size images visually consistent on the display width.
  esp_jpeg_image_cfg_t decodeCfg = infoCfg;
  decodeCfg.out_scale = JPEG_IMAGE_SCALE_0;
  decodeCfg.flags.swap_color_bytes = 1;

  esp_jpeg_image_output_t scaledInfo = {};
  err = esp_jpeg_get_image_info(&decodeCfg, &scaledInfo);
  if (err != ESP_OK) {
    Serial.printf("esp_jpeg_get_scaled_info failed: 0x%x\r\n", (unsigned)err);
    free(jpegData);
    return false;
  }

  uint16_t *decoded = static_cast<uint16_t *>(ps_malloc(scaledInfo.output_len));
  if (!decoded) {
    free(jpegData);
    return false;
  }

  decodeCfg.outbuf = reinterpret_cast<uint8_t *>(decoded);
  decodeCfg.outbuf_size = scaledInfo.output_len;

  err = esp_jpeg_decode(&decodeCfg, &scaledInfo);
  free(jpegData);
  if (err != ESP_OK) {
    Serial.printf("esp_jpeg_decode failed: 0x%x\r\n", (unsigned)err);
    free(decoded);
    return false;
  }

  Serial.printf("JPEG decoded: original=%ux%u scaled=%ux%u scale=%u len=%u\r\n",
                originalInfo.width, originalInfo.height, scaledInfo.width, scaledInfo.height,
                (unsigned)decodeCfg.out_scale, (unsigned)scaledInfo.output_len);
  drawScaledRgb565Be(decoded, scaledInfo.width, scaledInfo.height);
  free(decoded);
  return true;
}

static bool drawPngImage(const String &path) {
  uint8_t *pngData = nullptr;
  size_t pngSize = 0;
  if (!readWholeFile(path, &pngData, &pngSize)) {
    Serial.printf("PNG read failed: %s\r\n", path.c_str());
    return false;
  }

  unsigned char *rgba = nullptr;
  unsigned pngW = 0;
  unsigned pngH = 0;
  // lodepng allocates the output buffer through LVGL memory because
  // LV_MEM_CUSTOM is enabled in build_opt.h.
  unsigned err = lodepng_decode32(&rgba, &pngW, &pngH, pngData, pngSize);
  free(pngData);

  if (err != 0 || !rgba) {
    Serial.printf("lodepng_decode32 failed: err=%u\r\n", err);
    return false;
  }

  Serial.printf("PNG decoded: %ux%u len=%u\r\n", pngW, pngH, (unsigned)(pngW * pngH * 4));

  drawScaledRgbaLvgl(rgba, pngW, pngH);

  lv_mem_free(rgba);
  return true;
}

static void drawCurrentImage() {
  if (imageCount == 0) return;
  if (!ensureFrameBuffer()) {
    showCenteredMessage("No PSRAM frame buffer");
    return;
  }

  String path = imagePathAt(imageIndex);
  Serial.printf("Show image %d/%u: %s, mode=WIDTH_FIT\r\n",
                imageIndex + 1, imageCount, path.c_str());

  clearFrameBuffer(RGB565_BLACK);
  bool ok = false;
  if (isJpegFile(images[imageIndex])) {
    ok = drawJpegImage(path);
  } else if (isPngFile(images[imageIndex])) {
    ok = drawPngImage(path);
  }

  if (ok) {
    presentFrameBuffer();
  } else {
    showCenteredMessage("Image decode failed");
  }
}

static void nextImage(int delta) {
  if (imageCount == 0) return;
  imageIndex = (imageIndex + delta + imageCount) % imageCount;
  imageNeedsRedraw = true;
}

static void pollImageTouch() {
  static bool wasPressed = false;
  static int16_t startX = 0;
  static int16_t startY = 0;
  static int16_t lastX = 0;
  static int16_t lastY = 0;

  bool pressed = touch.touched();
  if (pressed) {
    CST_TS_Point point = touch.getPoint();
    lastX = constrain(point.x, 0, (int16_t)gfx->width() - 1);
    lastY = constrain(point.y, 0, (int16_t)gfx->height() - 1);
    if (!wasPressed) {
      startX = lastX;
      startY = lastY;
      wasPressed = true;
    }
    return;
  }

  if (!wasPressed) return;
  wasPressed = false;

  int16_t dx = lastX - startX;
  int16_t dy = lastY - startY;

  // Horizontal swipes change image. The threshold avoids accidental changes
  // from taps or mostly vertical drags.
  if (abs(dx) > 60 && abs(dx) > abs(dy)) {
    nextImage(dx < 0 ? 1 : -1);
  }
}

static bool isImageFile(const char *name) {
  String lower(name);
  lower.toLowerCase();
  return isImageFile(lower);
}

static void scanImages() {
  imageCount = 0;
  if (!sdReady) return;
  File dir = SD_MMC.open(IMAGE_DIR);
  if (!dir || !dir.isDirectory()) return;
  // Store only file names. Full paths are rebuilt later so the array stays
  // compact and path handling matches the ESP-IDF example's /images folder.
  for (File f = dir.openNextFile(); f && imageCount < MAX_IMAGES; f = dir.openNextFile()) {
    String name = baseNameOf(f.name());
    if (!f.isDirectory() && isImageFile(name)) {
      images[imageCount++] = name;
    }
    f.close();
  }
  sortImages();
}

static void buildUi() {
  lv_obj_t *scr = lv_scr_act();
  lv_obj_clean(scr);
  lv_obj_clear_flag(scr, LV_OBJ_FLAG_SCROLLABLE);

  if (!sdReady) {
    showLvglPrompt(scr, "No SD card detected. Please insert it and then power on again.");
  } else if (imageCount == 0) {
    showLvglPrompt(scr, "Image not found.");
  } else {
    // Image pixels are drawn directly from the PSRAM frame buffer. Avoid LVGL
    // refreshes over the image page, otherwise LVGL can overwrite the LCD.
    imageBrowserMode = true;
    imageNeedsRedraw = true;
  }
}

void setup() {
  boardBegin();
  mountSdCard();
  scanImages();
  buildUi();
  // Render the initial LVGL prompt immediately when there is no image browser.
  if (!imageBrowserMode) lv_timer_handler();
  if (imageNeedsRedraw) {
    imageNeedsRedraw = false;
    drawCurrentImage();
  }
}

void loop() {
  static uint32_t lastMs = millis();
  uint32_t now = millis();
  lv_tick_inc(now - lastMs);
  lastMs = now;
  if (imageBrowserMode) {
    // In image mode the LCD is owned by the direct renderer, not LVGL.
    pollImageTouch();
  } else {
    lv_timer_handler();
  }
  if (imageNeedsRedraw) {
    imageNeedsRedraw = false;
    drawCurrentImage();
  }
  delay(5);
}

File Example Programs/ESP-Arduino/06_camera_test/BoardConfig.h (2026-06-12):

#pragma once

#include <Arduino.h>

static const uint8_t NEXTION_IIC_SCL_PIN = 7;
static const uint8_t NEXTION_IIC_SDA_PIN = 8;

static const uint16_t LCD_H_RES = 240;
static const uint16_t LCD_V_RES = 320;

static const int8_t LCD_SCLK_PIN = 5;
static const int8_t LCD_MOSI_PIN = 1;
static const int8_t LCD_MISO_PIN = -1;
static const uint8_t LCD_DC_PIN = 3;
static const uint8_t LCD_CS_PIN = 2;
static const uint8_t LCD_BL_PIN = 6;

static const uint8_t CST826_ADDR = 0x15;
static const uint8_t PCF8574_ADDR = 0x38;

static const uint8_t PCF8574_PIN_CAM_PWDN = 4;
static const uint8_t PCF8574_PIN_LCD_RST = 6;

static const int8_t CAM_PWDN_GPIO = -1;
static const int8_t CAM_RESET_GPIO = -1;
static const uint8_t CAM_XCLK_GPIO = 38;
static const uint8_t CAM_SIOD_GPIO = 8;
static const uint8_t CAM_SIOC_GPIO = 7;
static const uint8_t CAM_Y9_GPIO = 21;
static const uint8_t CAM_Y8_GPIO = 39;
static const uint8_t CAM_Y7_GPIO = 40;
static const uint8_t CAM_Y6_GPIO = 42;
static const uint8_t CAM_Y5_GPIO = 46;
static const uint8_t CAM_Y4_GPIO = 48;
static const uint8_t CAM_Y3_GPIO = 47;
static const uint8_t CAM_Y2_GPIO = 45;
static const uint8_t CAM_VSYNC_GPIO = 17;
static const uint8_t CAM_HREF_GPIO = 18;
static const uint8_t CAM_PCLK_GPIO = 41;

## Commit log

2026-04-02 init repository
    [ONX2432G028_2D_File.dwg, partitions.csv]
2026-06-12 Add ESP-Arduino examples and update README
